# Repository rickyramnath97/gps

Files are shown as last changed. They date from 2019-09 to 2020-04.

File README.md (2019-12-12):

# Build Instructions for Raspberry Pi GPS Sensor

## Table of Contents
1. [Introduction](#introduction)
2. [Material Requirements](#material-requirements)
3. [Raspberry Pi Configuration](#raspberry-pi-configuration)
4. [Mechanical Assembly and Soldering](#mechanical-assembly-and-soldering)
5. [SPI/UART Connection](#spi/uart-connection)
6. [Power Up](#power-up)
7. [Explore with your Sensor](#explore-with-your-sensor)

### Introduction
GPS sensors are receivers with antennas that use a satellite-based navigation system with a network of 24 satellites in orbit around the earth to provide position, velocity, and timing information. The breakout is built around the MTK3339 chipset, a high-quality GPS module that can track up to 22 satellites on 66 channels, has an excellent high-sensitivity receiver (-165 dBm tracking!), and a built in antenna. It can do up to 10 location updates a second for high speed, high sensitivity logging or tracking. Power usage is incredibly low, only 20 mA during navigation. The following instructions are provided to assist you in developing a GPS sensor that can measure longitude, latitude and many other readings.
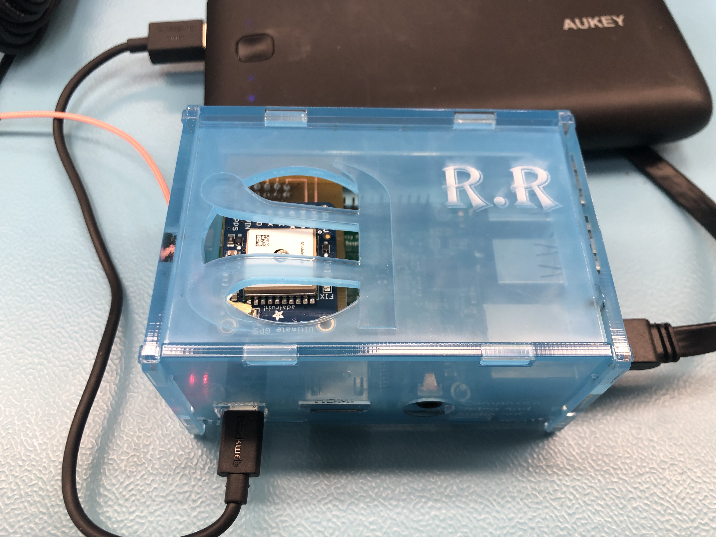
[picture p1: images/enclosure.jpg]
<br/></p>

> I recommend that before attempting this build that you have accomplished watching videos on [soldering](https://youtu.be/3230nCz3XQA). 

### Material Requirements
The project's total budget will cost you approx. CAD$218.41 including tax and shipping. The prices can be converted depending on where you are from. If you would like to see my personal budget click [here](https://github.com/rickyramnath97/gps/blob/master/documentation/Rickys%20Budget.xlsx). Keep in mind that my budget costs lower because I own some of the parts (or had access to in Prototype Lab) from the list.
The following links below are sources of where you can purchase the items:
* [Raspberry Pi 3 Kit](https://www.canakit.com/raspberry-pi-3-ultimate-kit.html) - CAD$89.95
* [Adafruit Ultimate GPS Breakout](https://www.adafruit.com/product/746) - CAD$39.95
* [40 Pin GPIO Connector Header](https://www.buyapi.ca/product/40-pin-gpio-connector-header/) - CAD$1.95
* [Break Away Headers - Straight](https://www.sparkfun.com/products/116) - CAD$2.01
* [Custom PCB](https://www.pcbway.com/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) - CAD$88.88 
<br/>Depending on the design of your PCB prices may vary. 
<br/>You can design your own PCB using [Fritzing](http://fritzing.org/download/) for free. 
<br/>Check out my design of the [PCB](https://github.com/rickyramnath97/gps/tree/master/electronics).
* [Safety Glasses](https://www.amazon.ca/3M-Virtua-Glasses-Polycarbonate-Anti-Scratch/dp/B00AEFBLW2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) - CAD$9.27

### Raspberry Pi Configuration
1. Create your Raspberry Pi's [image](https://github.com/six0four/StudentSenseHat/blob/master/cribpisdcard.md) for your project.

### Mechanical Assembly and Soldering
1. Make sure to break the 9 pins from the Break Away Header. Then start by soldering the sensor to the pins of the header. 
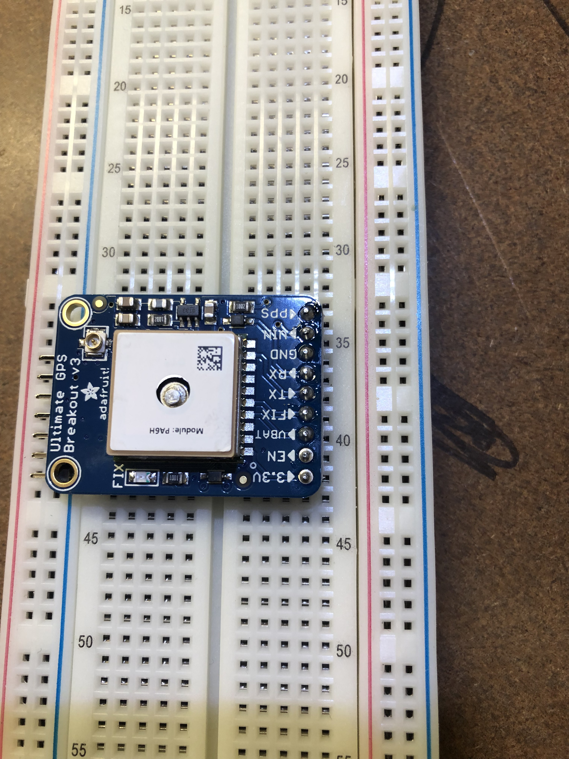
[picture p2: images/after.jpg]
<br/>

2. You can design your own PCB using [Fritzing software](http://fritzing.org/download/) for free or my version of the [fritzing file](https://github.com/rickyramnath97/gps/tree/master/electronics). You can refer to the image of the schematic and PCB designs below.
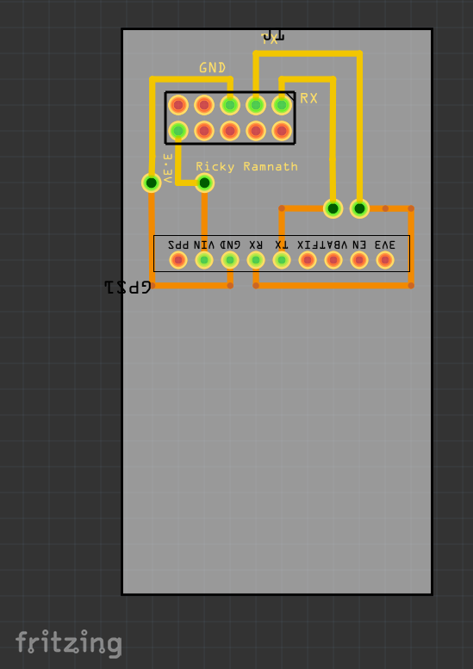
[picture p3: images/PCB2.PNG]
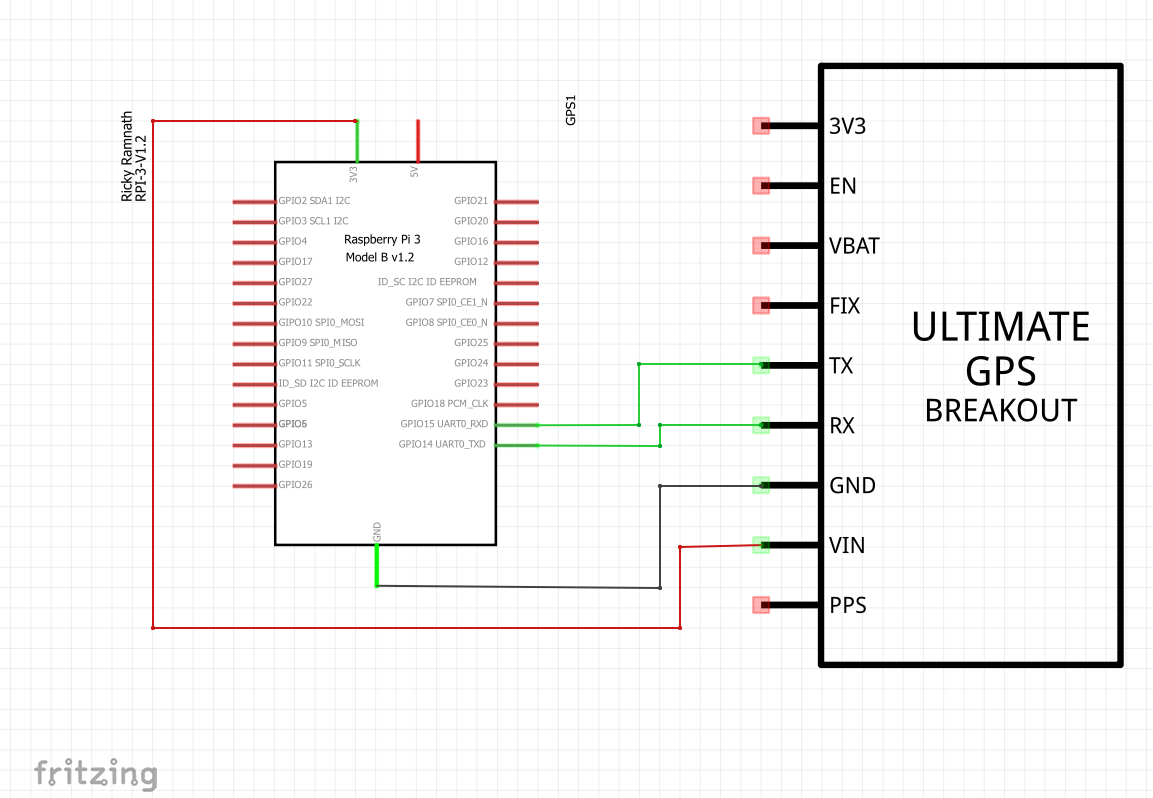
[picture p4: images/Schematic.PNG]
<br/> 
<br/>Here are the following pins that you should know for this project:
##### Power Pins
* VIN - Power Pin
  *GPS Vin  to 3.3V (red wire)
* GND - common ground for power and logic

##### Logic Pins
* RX pin
	* GPS RX to TX on Pi
* TX pin
	* GPS TX to RX on Pi

3. Once you have obtained your PCB board solder the following:
* Vias\*
* 40-pin socket 
* 9-pin socket
<br/>\*Note: You must thread a single strand of wire through the holes, solder it, and then cut the remaining wires off.

Once you have finished soldering, your board should look like this along with the sensor:
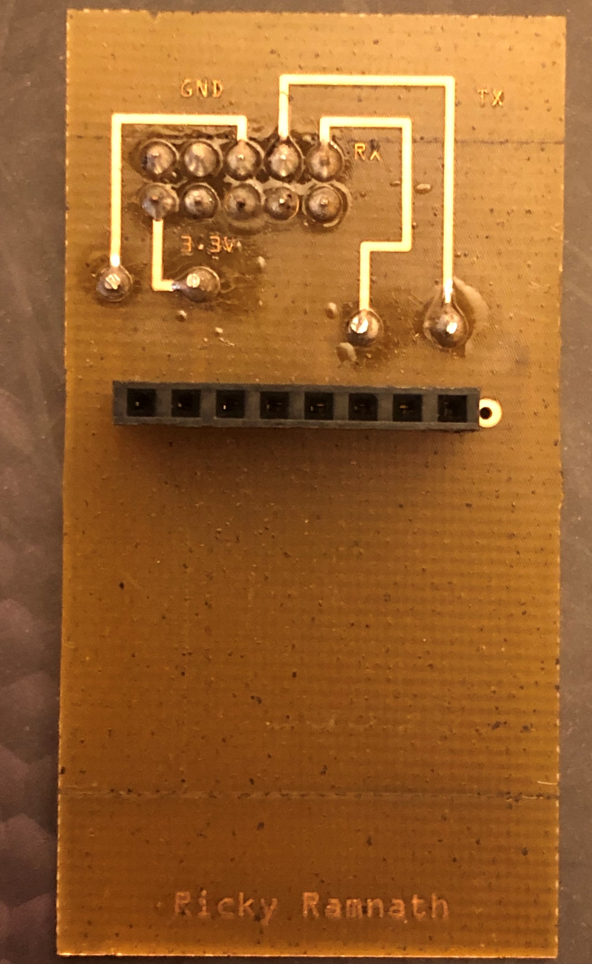
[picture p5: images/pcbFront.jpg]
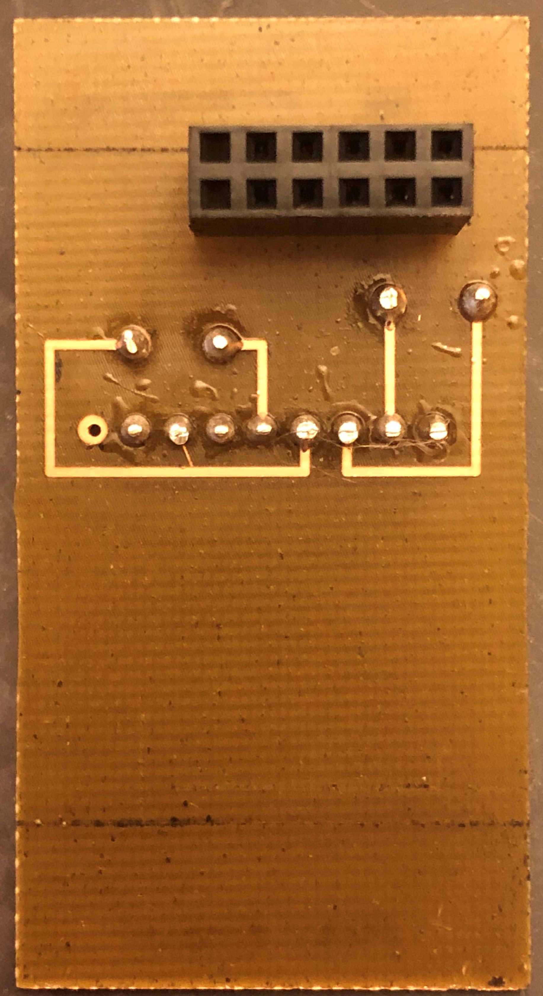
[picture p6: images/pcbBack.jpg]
<br/><br/>

### SPI/UART Connection

1. In order for the sensor to work, you have to Disable Serial console and Enable UART on your Pi. By running <b>sudo raspi-config</b> in the terminal window. Next goto <b>Interfacing Options -> Serial -> Select "No" on enabling the login shell -> Select "Yes" on enabling serial port hardware</b>
This is what it should look like:
<br/>

### Power Up

1. Now you can test the sensor and get readings by typing in the following:
```
sudo killall gpsd
```
```
sudo gpsd /dev/serial0 -F /var/run/gpsd.sock
```
```
cgps -s
```
You should see something like this:
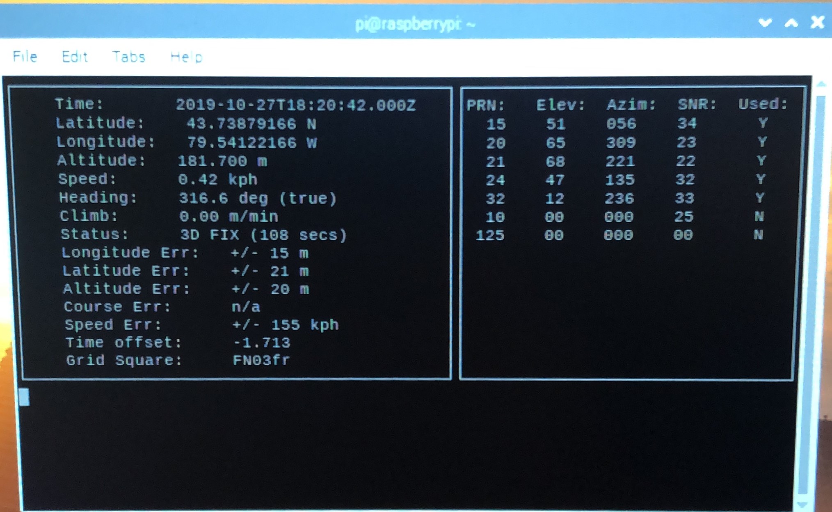
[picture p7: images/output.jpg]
<br/>

### Explore with your Sensor
You can now conduct experiments with your GPS sensor. 

By following these instructions, this project can be reproducible by anybody that has a basic understanding of computers and hardware.

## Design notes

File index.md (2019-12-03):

<h3 id="december-03-2019-week-13">December 3, 2019 (Week 13)</h3>
<p>Presentation Day + Update on Project</p>

<p>Today I presented my final hardware project. I also had to update something in m project. </p>

<p>I needed to get a faster fix for my sensor. In order to combat that I used another type of antenna that I had at home that came with my surveillance camera system. This antenna was able to get a better fix with my GPS due to the protruding antenna. </p>

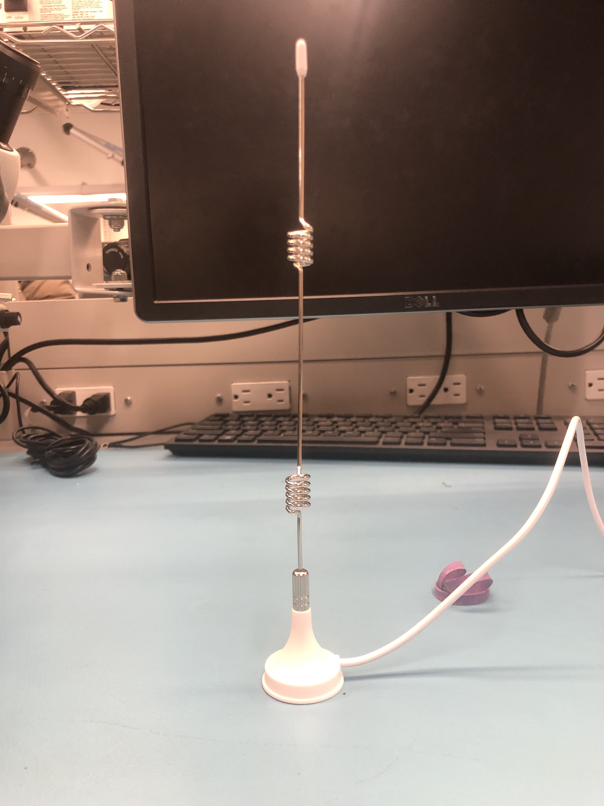
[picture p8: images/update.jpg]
<br/>

<p>I am also working on my README.md file to conclude this semester with. </p>

<hr size="10" width="100%" align="center" color="green">
<h3 id="november-26-2019-week-12">November 26, 2019 (Week 12)</h3>

<p>Presentation Due</p>

<p>This has been an amazing semester. Ive learned alot of new skills.</p>
<p>To conclude this semester, I made a powerpoint presentation which will be graded.</p>
<p>You can view the presentation <a href="https://github.com/rickyramnath97/gps/blob/master/documentation/MTK3339%20%E2%80%93%20Adafruit%20Ultimate%20GPS%20Sensor.pptx">here</a></p>

<hr size="10" width="100%" align="center" color="green">
<h3 id="november-19-2019-week-11">November 19, 2019 (Week 11)</h3>
<p>Enclosure Due</p>
<p>This week I am showing that my Enclosure is due. I used CorelDRAW and some of the internet to help me design my case. You can view my design file <a href="https://github.com/rickyramnath97/gps/blob/master/mechanical/RickysPi3Case%20New.cdr">here</a></p>

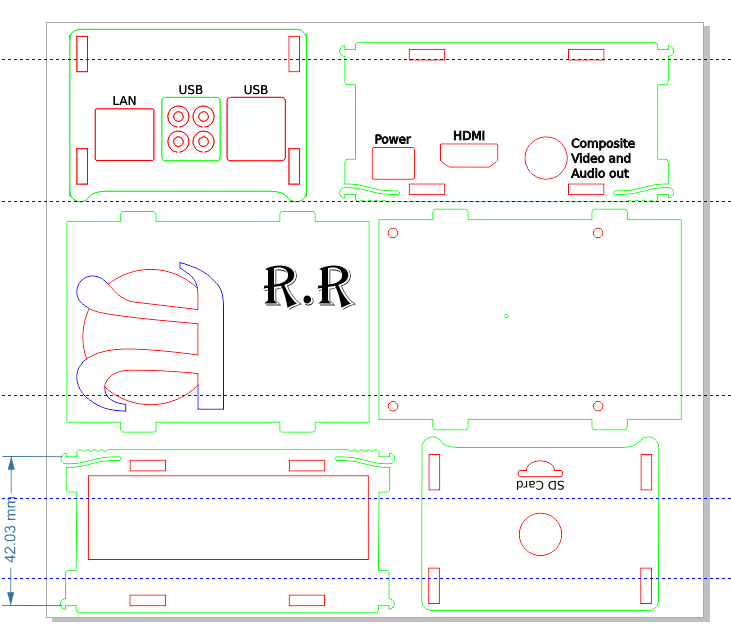
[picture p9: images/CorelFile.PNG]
Schematic

Enclosure

<hr size="10" width="100%" align="center" color="green">
<h3 id="november-12-2019-week-10">November 12, 2019 (Week 10)</h3>
<p> PCB Power Up </p>
<p> This week I powered up my PCB and tested it. I was having some trouble aquiring signal for my GPS at school. I have found a spot where is located in the prototype lab where it has worked before. I am still actively looking and trying to find "sweet spots" around the vicinity of the class room and inside the prototype lab. So far everything is working fine though. </p>
<p> Referring to my Gantt Chart, I am up to date with everything and I am in the process of making my enclosure for my RPi which is due next week and will be graded. </p>
<p> Below you can see a video of my sensor working with my PCB. </p>
<video width="420" height="420" controls>
  <source src="videos/PCB_PowerUp.mp4" type="video/mp4">
  Your browser does not support HTML5 video.
</video>

<hr size="10" width="100%" align="center" color="green">
<h3 id="november-5-2019-week-9">November 5, 2019 (Week 9)</h3>
<p> Soldering Milestone </p>
<p> Soldered up my PCB Board that was made in the Protoype Lab </p>
<p> According to my Gantt Chart, I am up to date with my progress and have my sensor and my connection from my laptop to my RPi working seemlessly. </p>
<p> This week I am working on designing my enclosure to fit my sensor and my Development Platform. I have done the Idea Lab Quiz and booked a session to get more information as to how it will all work. </p>
<p> Below are photos of my PCB soldered up. I used a 8-Pin Stackable Header to harness my GPS Sensor, and used a 6x2 Stackable Header to plug into my RPi. All the connections are flawless. There are no bridges. To test it, I used my digital multimeter to test continuity to see if any contacts are bridged. </p>
Front of PCB
Back of PCB

<hr size="10" width="100%" align="center" color="green">
<h3 id="october-29-2019-week-8">October 29, 2019 (Week 8)</h3>
<p> Breadboarded Milestone: This week I successfully breadboarded and demostrated my sensor in front of my Professor(Kristian). I also spent some time in the prototype lab with Kelly and Kristian to set up my RPI to get it to connected to my laptop using a ethernet cable and adapter (was a success). So far, from refering to my Gantt Chart, I am on track with all my milestones and achievements. </p>
<p> Sensor Breadboarded: </p>
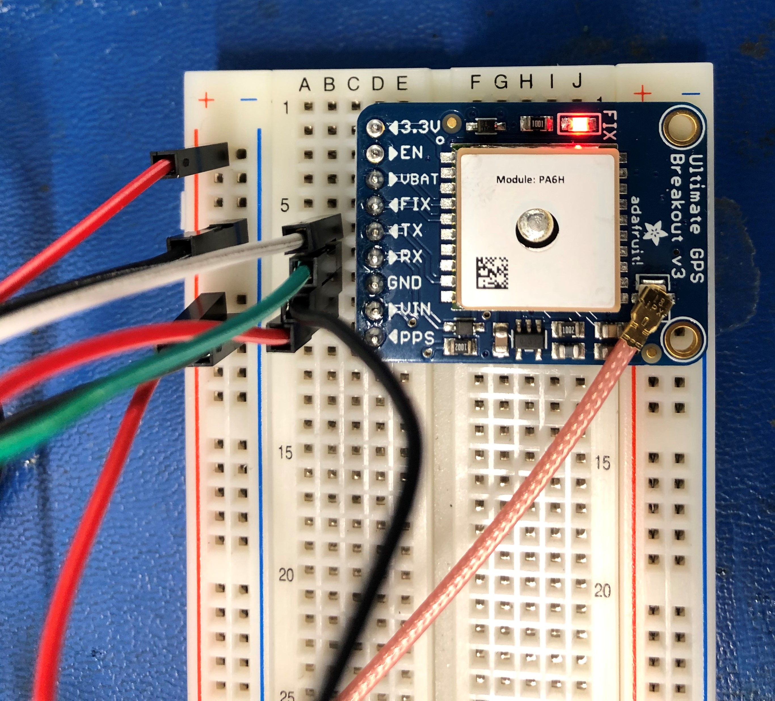
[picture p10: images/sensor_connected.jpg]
Connected Sensor

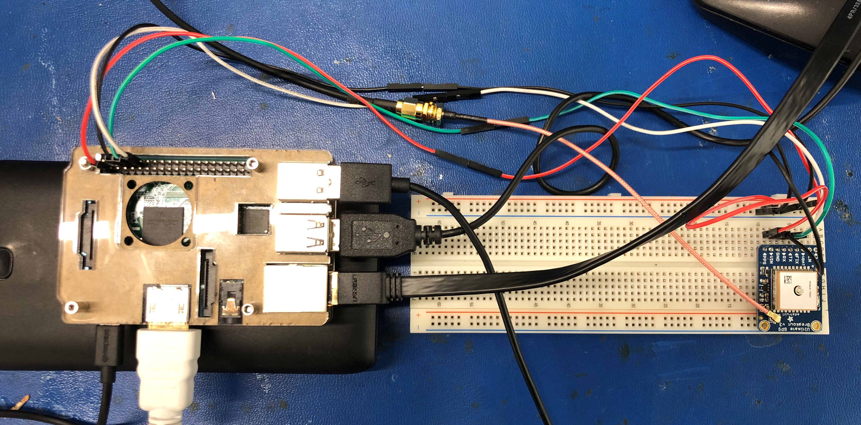
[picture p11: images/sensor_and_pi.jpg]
Sensor and Pi


<p> In order for my sensor to work, I had to Disable Serial console and Enable UART on my Pi. By running <b>sudo raspi-config</b> in the terminal window. Next I went to <b>Interfacing Options -> Serial -> Select "No" on enabling the login shell -> Select "Yes" on enabling serial port hardware</b></p>
<p> This is what I got: </p>
Config

<p> Next I ran a few commands to get the the sensor to display its respective results: </p>
<p><b> sudo killall gpsd </b></p>
<p><b> sudo gpsd /dev/serial0 -F /var/run/gpsd.sock </b></p>
<p><b> cgps -s </b></p>

<p> These are the results I got: </p>
Output
<hr size="10" width="100%" align="center" color="green">
<h3 id="october-15-2019-week-7">October 15, 2019 (Week 7)</h3>
<p> PCB Designed </p>
<p> Designed my PCB, Schematic, and Breadboard Design. I also sent my gerber files to the Prototype Lab. You can view my fritzing file <a href="https://github.com/rickyramnath97/gps/blob/master/electronics/GPS%20Fritzing2.fzz">here</a>. </p>
<p> I am also getting my Broadcom Development Platform set up with VNC Viewer to work with the Humber College WiFi network. </p> 
<p>PCB Designed: </p>
Image of PCB
<p>Schematic: </p>
Image of Schematic
<p>Breadboard Design: </p>
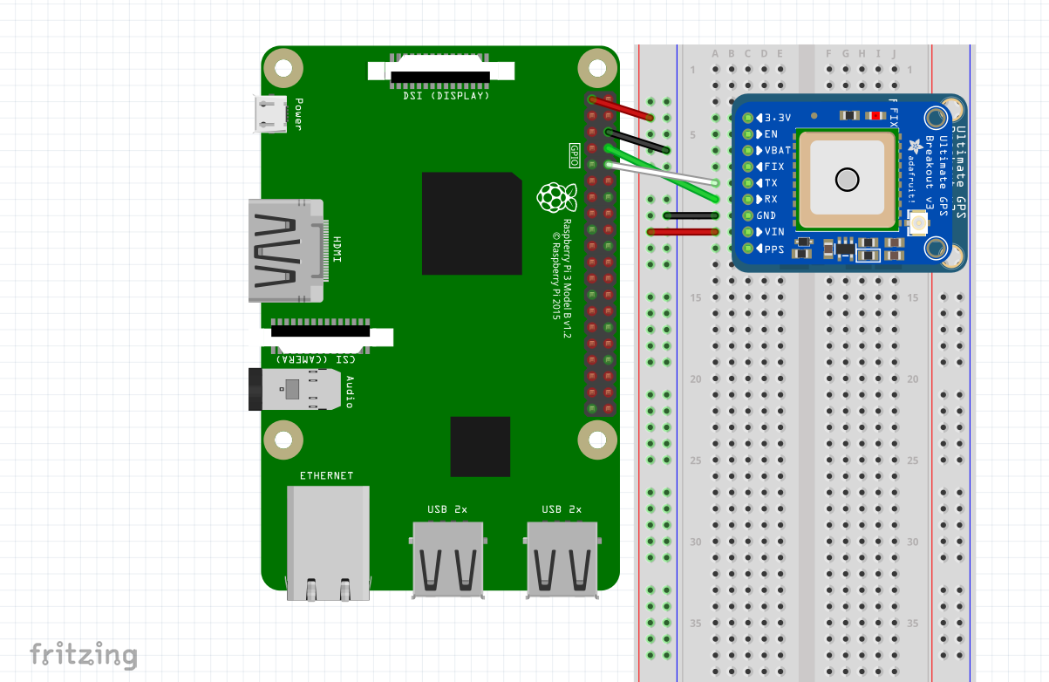
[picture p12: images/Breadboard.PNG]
Image of Breadboard


<hr size="10" width="100%" align="center" color="green">

<h3 id="october-8-2019-week-6">October 8, 2019 (Week 6)</h3>
<p> Showing my acquisitions </p>
<p> Package arrived Thursday, October 3rd, 2019: </p>
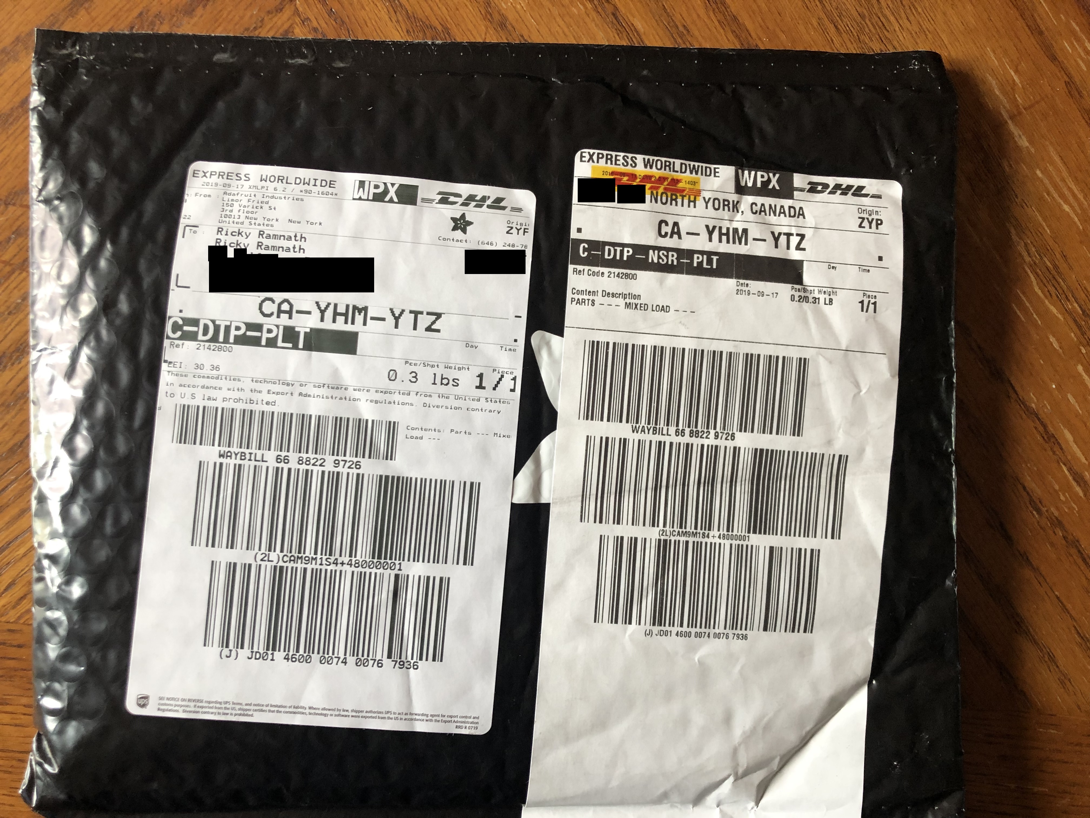
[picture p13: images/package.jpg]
Image of Package


<p> Contents of package include; GPS Sensor, Adapter cable for antenna, and antenna: </p>

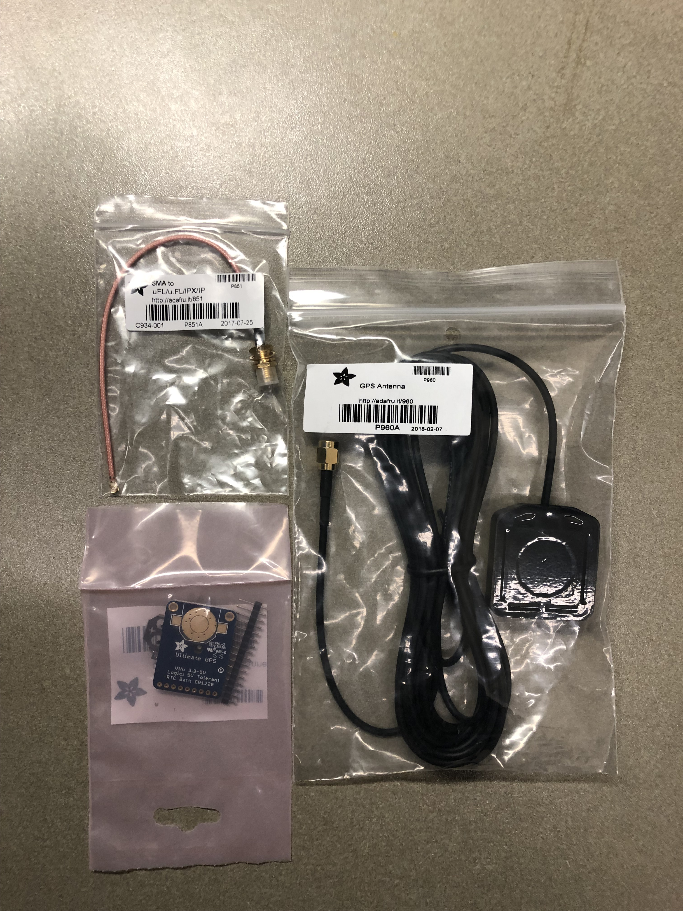
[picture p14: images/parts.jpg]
Image of parts


<p> I had also watched a <a href="https://youtu.be/3230nCz3XQA">video</a> on how to solder my header pins and was able to do so. I used my own Lead Free solder with Rosin Core and a soldering iron that I had borrowed from work. This was the outcome:</p>

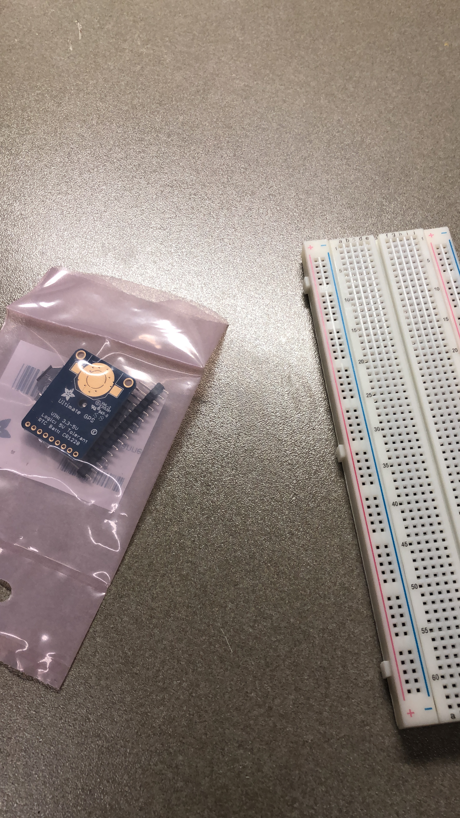
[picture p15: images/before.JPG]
Image of parts


Image of parts

<hr size="10" width="100%" align="center" color="green">

<h3 id="october-1-2019-week-5">October 1, 2019 (Week 5)</h3>
<p> Setting up my broadcom development platform (RPI) </p>
<p> Parts Ordered </p>

<p> Proof of Purchase: </p>
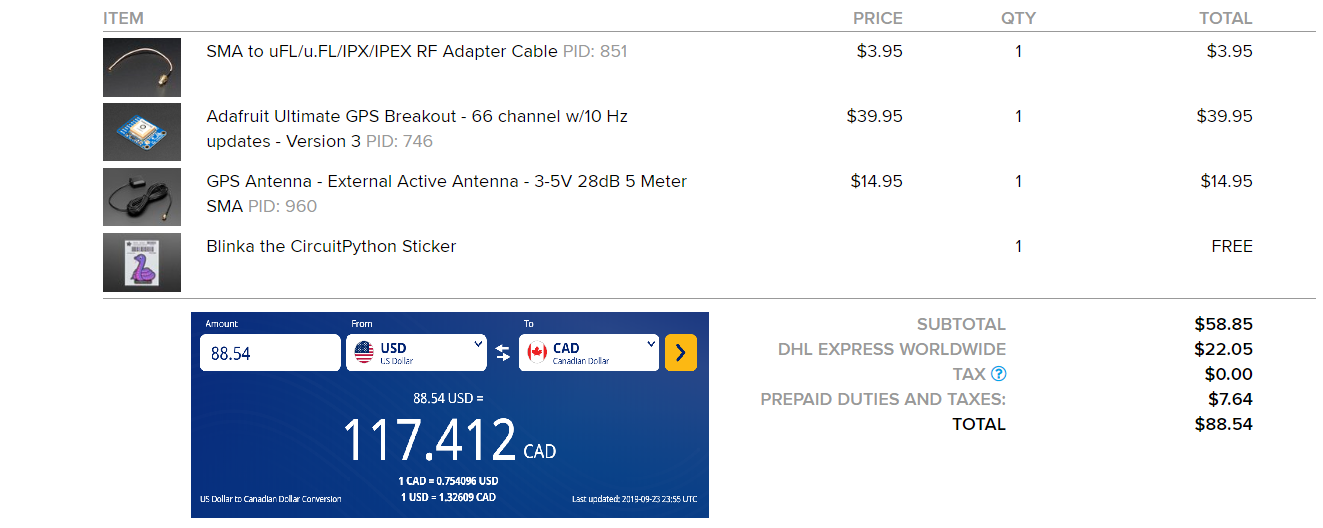
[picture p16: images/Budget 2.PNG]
Image of Budget


<hr size="10" width="100%" align="center" color="green">

<h3 id="september-24-2019-week-4">September 24, 2019 (Week 4)</h3>
  
<p><a href="https://github.com/rickyramnath97/gps/blob/master/documentation/Rickys%20Budget.xlsx">Budget Completed!</a>.</p>
  <p>- Ordered Parts</p>

<hr size="10" width="100%" align="center" color="green">

<h3 id="september-17-2019-week-3">September 17, 2019 (Week 3)</h3>
   
<p><a href="https://github.com/rickyramnath97/gps/blob/master/documentation/CENG317%20Project%20Plan.gan">Gantt Chart Completed!</a></p>
 <p>- Met with collaborators </p> 
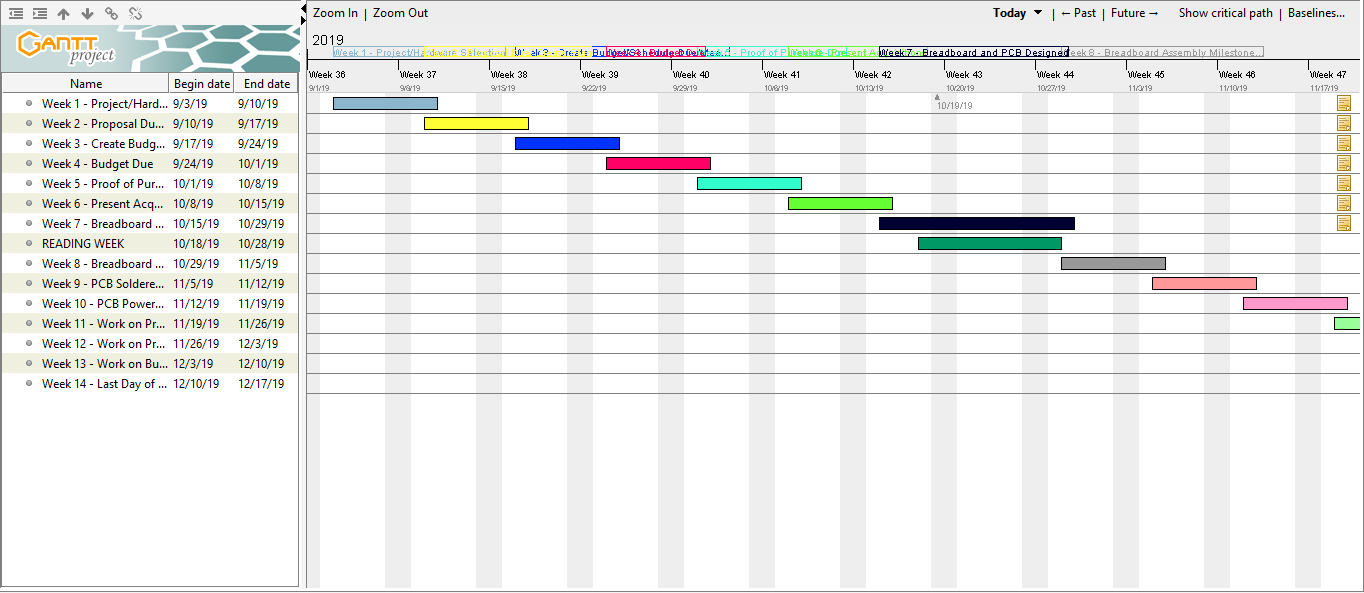
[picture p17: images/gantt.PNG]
Gantt


<hr size="10" width="100%" align="center" color="green"> 
  
<h3 id="september-09-2019-week-2">September 9, 2019 (Week 2)</h3>

<p> Handed in <a href="https://github.com/rickyramnath97/gps/blob/master/documentation/ProposalContentStudentNameRev03.xlsx">proposal</a>. </p>

<p> For my hardware, I chose the Adafruit Ultimate GPS Breakout. This will be able to display location. My goal is to make the project scalable from one location to several for our Capstone Project. To enhance the user experience, having a GPS Sensor is crucial to detect which parts crib data belong to which. Additionally, the GPS will prioritize orders by accessing location from students and finding out how long it will take for student to arrive to the parts crib. From that we will know which orders to get ready first in priority sequence based on travel time. </p>

<p> Image of Sensor: </p>
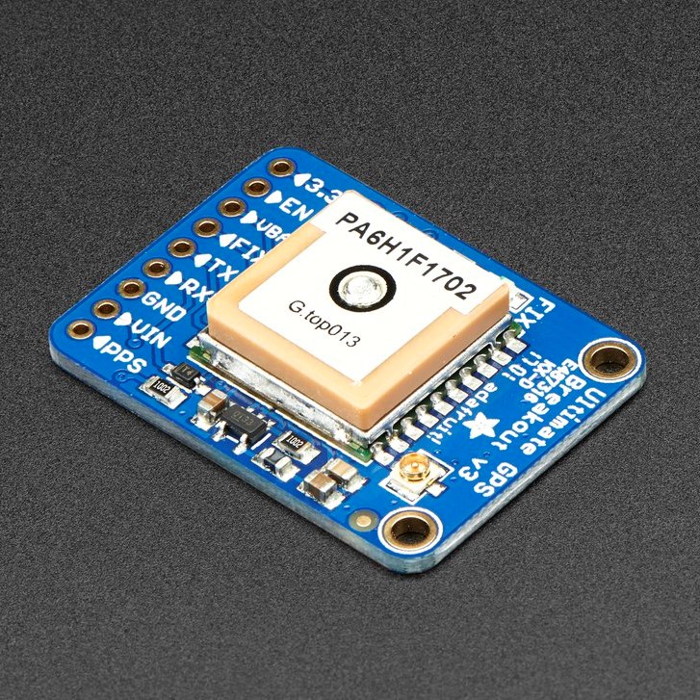
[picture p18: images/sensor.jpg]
Image of Sensor


<p> Working on Gantt Chart </p>

<hr size="10" width="100%" align="center" color="green">

<h3 id="september-03-2019-week-1">September 3, 2019 (Week 1)</h3>

<p>Welcome! </p>
<p>Repo Created! </p>

<p>Created <a href="https://github.com/rickyramnath97/gps/blob/master/documentation/ProposalContentStudentNameRev03.xlsx">proposal</a>.</p>

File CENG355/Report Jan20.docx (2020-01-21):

Ricky Ramnath

Humber College Parts Crib Management Solution

Status

/1 Hardware present?

/1 Title Page

/1 Declaration of Joint Authorship

/1 Proposal (500 words)

/1 Executive Summary

# Declaration of Joint Authorship

We, Student A, Student B, and Student C, confirm that this work submitted is the joint work of our group and is expressed our own words. Any uses made within it of the works of any other author, in any form (ideas, equations, figures, texts, tables, programs), are properly acknowledged at the point of use. A list of the references used is included. The work breakdown is as follows: Each of us provided functioning, documented hardware for a sensor or effector. Student A provided RFID Scanner. Student B provided GPS Sensor. Student C provided 12- Button Keypad. In the integration effort Student A is the lead for further development of our mobile application, Student B is the lead for the Hardware, and Student C is the lead for connecting the two via the Database.

# Proposal

We have created a mobile application, worked with databases, completed a software engineering course, and prototyped a small embedded system with a custom PCB as well as an enclosure (3D printed/laser cut). Our Internet of Things (IoT) capstone project uses a distributed computing model of a smart phone application, a database accessible via the internet, an enterprise wireless (capable of storing certificates) connected embedded system prototype with a custom PCB as well as an enclosure (3D printed/laser cut), and are documented via this technical report targeting OACETT certification guidelines.

Intended project key component descriptions and part numbers
Development platform:
Sensor/Effector 1: RFID Scanner
Sensor/Effector 2: GPS Sensor
Sensor/Effector 3: 12 Button Keypad

We will continue to develop skills to configure operating systems, networks, and embedded systems using these key components to create an easier and more efficient method for allowing students to borrow parts from The Parts Crib. This project consists of both a web application and a mobile application with our sensors/effectors. The mobile application provides convenient access for students. This will be beneficial to students as they will be able to utilize the app to find parts that are available. They will be able to view the inventory of available parts which they can borrow if they wish, by using their student credentials. The web application will be utilized mainly by administrative users to keep track of inventory. The overall goal of this project is to avoid overcrowding in The Parts Crib during peak hours of the lab, keep track of parts that have yet to be returned by certain students based on their student credentials and to keep track of the remaining inventory. The RFID Scanner will be used to scan in and out parts that will be recorded on the online database which helps to provide inventory status. The GPS Sensor will prioritize the orders by location and help to identify a more specific location for The Parts Crib. The 12 Button Keypad will be used to get new registered users to type in a specific randomly generated code into the application upon registration to verify that they identify as a Humber College Student.

Our project description/specifications will be reviewed by, _____, ideally an employer in a position to potentially hire once we graduate. They will also ideally attend the ICT Capstone Expo to see the outcome and be eligible to apply for NSERC funded extension projects. This typically means that they are from a Canadian company that has been revenue generating for a minimum of two years and have a minimum of two full time employees.

The small physical prototypes that we build are to be small and safe enough to be brought to class every week as well as be worked on at home. In alignment with the space below the tray in the Humber North Campus Electronics Parts kit the overall project maximum dimensions are 12 13/16" x 6" x 2 7/8" = 32.5cm x 15.25cm x 7.25cm.

Keeping safety and Z462 in mind, the highest AC voltage that will be used is 16Vrms from a wall adapter from which +/- 15V or as high as 45 VDC can be obtained. Maximum power consumption will not exceed 20 Watts. We are working with prototypes and that prototypes are not to be left powered unattended despite the connectivity that we develop.

# Executive Summary

Explain what accomplishments are described by this document and why your product should be purchased and you should be hired by an investor.

# List of Figures

# 1.0 Introduction

This technical report presents the methods and processes of how we achieved our project result. Knowing who arrives, borrows parts and having easy access to our inventory are key parts of the parts crib management solution. Some of this projects policy require that you track how long students are borrowing parts for or that all students participating return each part at a certain time of day that is specified. This will additionally be able to help the administrative side by verifying that individuals borrowing parts are Humber College students that have an official student ID card. By recording sign-out times, it’s easy to track who borrows parts when and attend to students who are over their time limit or that have not yet returned said parts. Having a GPS sensor to track activity from a certain parts crib location and prioritize orders will also help with an efficient way of managing the parts crib. To further enhance security, the keypad will allow students to enter the specific code that will be generated by the application to ensure verification of Humber students. Finally, the RFID scanner will be a critical component of this project to help keep track of inventory by uploading information to the database for a more accurate count and to easily monitor activity. The application will provide a precise GPS location of the parts cribs, inventory status, and peak times for labs. The application will also allow students to create a cart of parts they will need for their labs and place orders from anywhere with a Wi-Fi connection. This system is meant for loan out companies and small businesses with inventory that will need to be loaned out to employees or customers. Specifically, this system will be prototyped and used by the Humber College Parts Crib.

## 1.1 Scope and Requirements

Describe what will be done. It is an Internet of Things (IoT) capstone project that uses a distributed computing model of a smart phone application, a database accessible via the internet, an enterprise wireless (capable of storing certificates) connected embedded system prototype with a custom PCB as well as an enclosure (3D printed/lasercut), and is documented via an OACETT certification acceptable technical report. Also describe the limits of the project and what will not be done (CSA testing) in this project. Include the development platform specifications and any other hardware specifications possibly organized in point form, the Android device requirements, and database specifications/protocols.

Report

/1 Hardware present?

/1 Introduction (500 words)

/1 Scope and Requirements

/1 Background (500 words)

/1 References

# 2.0 Background

We would like to thank mentor Diego Magalhães from AWS for supporting this project. This section is to include at least three references, here is an example of an APA citation of a website (OACETT, 2017) followed by a sentence citing an Article in a Periodical, a Book, and a Journal Article. Humber is planning to host an internal DeepRacer event using an existing example of machine learning (Robuck, 2018), artificial intelligence (Media, O., 2019), and internet connected servers (Kinsella, 2019).

# 3.0 Methodology

## 3.1 Required Resources

Report

/1 Parts/components/materials (500 words)

/1 PCB, case (500 words)

/1 Tools, facilities (500 words)

/1 Shipping, duty, taxes (250 words)

/1 Working time versus lead time (250 words)

### 3.1.1 Parts, Components, Materials

### 3.1.2 Manufacturing

### 3.1.3 Tools and Facilities

### 3.1.4 Shipping, duty, taxes

### 3.1.5 Time expenditure

Working time versus lead time.

## 3.2 Development Platform

### 3.2.1 Mobile Application

Status

/1 Hardware present?

/1 Memo by student A + How did you make your Mobile Application? (500 words)

/1 Login activity

/1 Data visualization activity

/1 Action control activity

Include screenshots such as Figure 1. Testing. Progress.

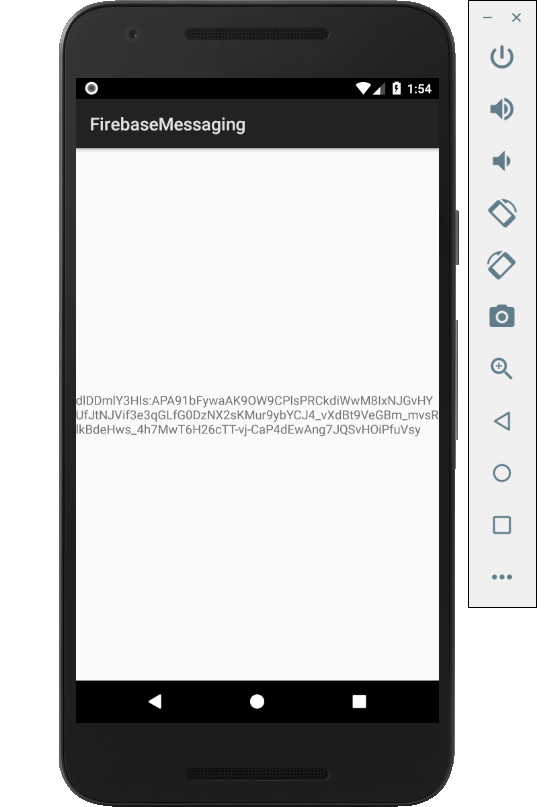
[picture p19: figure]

Figure 1. By Android Studio - https://developer.android.com/studio/, CC BY-SA 4.0, https://commons.wikimedia.org/w/index.php?curid=74094999

### 3.2.2 Image/firmware

Status

/1 Hardware present?

/1 Memo by student B + How did you make your Image/firmware? (500 words)

/1 Code can be run via serial or remote desktop

/1 Wireless connectivity

/1 Sensor/effector code on repository

### 3.2.3 Breadboard/Independent PCBs

Status

/1 Hardware present?

/1 Memo by student C + How did you make your hardware? (500 words)

/1 Sensor/effector 1 functional

/1 Sensor/effector 2 functional

/1 Sensor/effector 3 functional

The initial schematic design, Figure 2, based on datasheets (Bosch Sensortec, 2019) led to a breadboard layout Figure 3 that was realized Figure 4.

How did you build your Prototype: Breadboard?

Then a PCB was designed, Figure 5, and populated (Figure 6). Bill of Materials, Case, Time commitment. Testing. Progress.

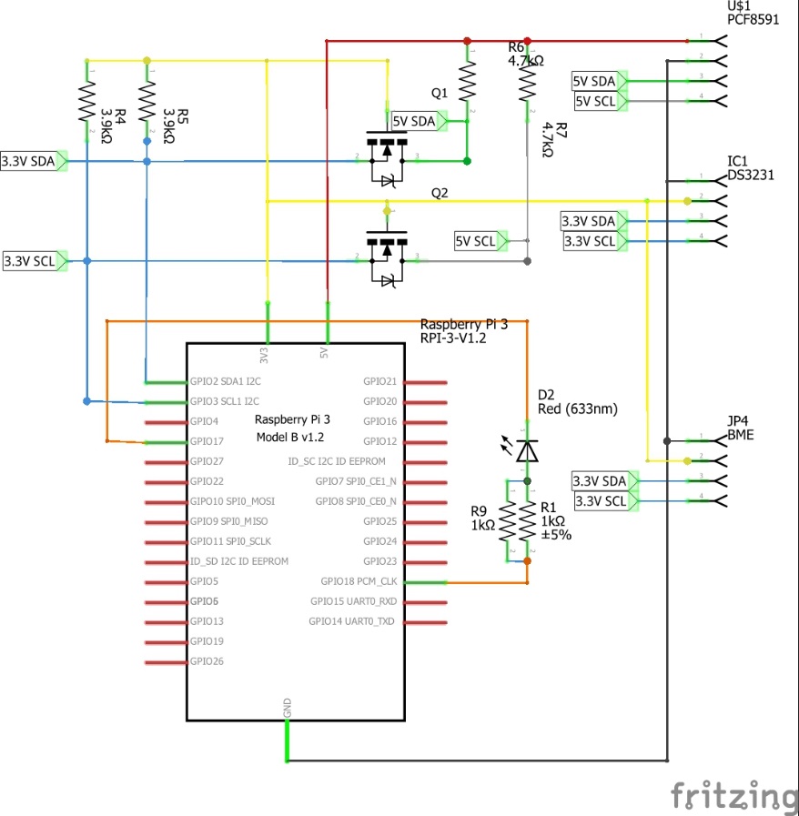
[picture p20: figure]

Figure 2. Initial schematic. This work is a derivative of "http://fritzing.org/parts/" by Fritzing, used under CC:BY-SA 3.0.

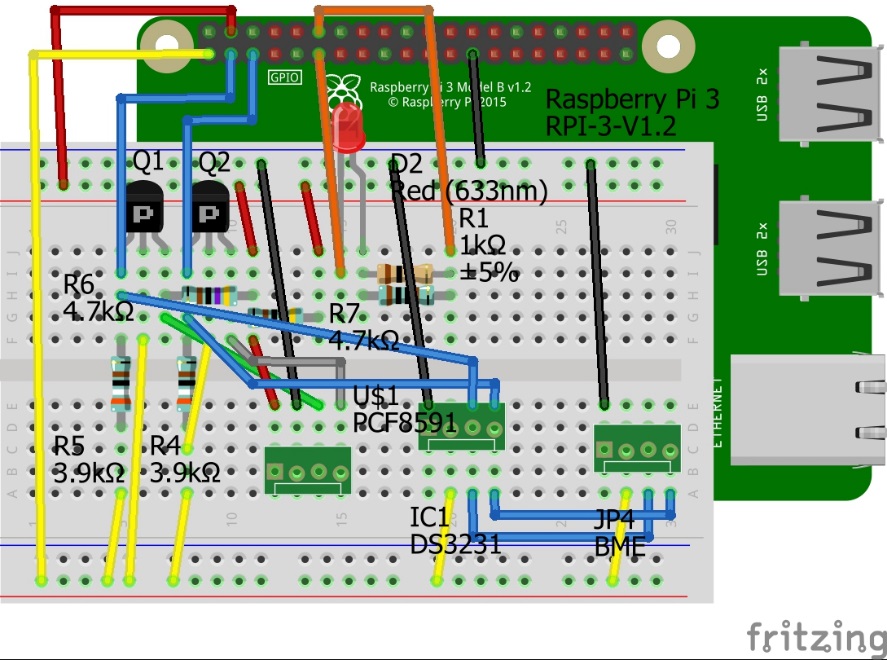
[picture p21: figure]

Figure 3. This work is a derivative of "http://fritzing.org/parts/" by Fritzing, used under CC:BY-SA 3.0.

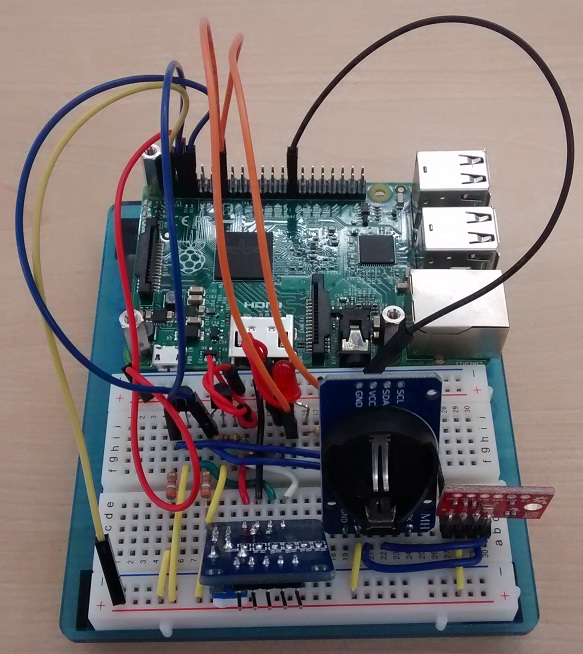
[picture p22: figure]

Figure 4. Breadboard prototype.

### 3.2.4 Printed Circuit Board

Demo

/1 Hardware present?

/1 PCB Complete and correct

/1 PCB Soldered wire visible but trim, no holes or vacancies

/1 PCB Tested with multimeter

/1 PCB Powered up

How did you build your Prototype: PCB?

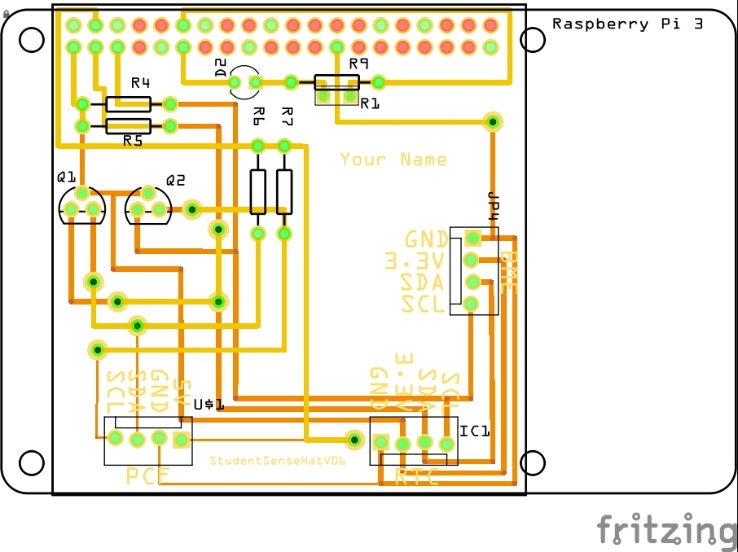
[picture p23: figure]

Figure 5. PCB design This work is a derivative of "http://fritzing.org/parts/" by Fritzing, used under CC:BY-SA 3.0.

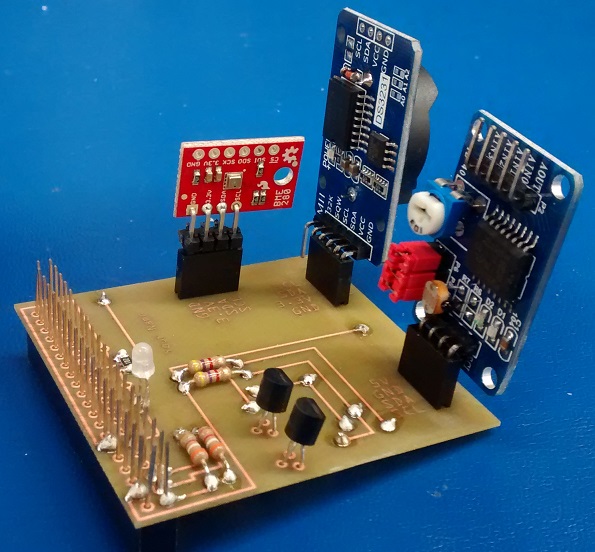
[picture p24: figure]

Figure 6. Humber Sense Hat Prototype PCB.

### 3.2.5 Enclosure

Demo

/1 Hardware present?

/1 Case encloses development platform and custom PCB.

/1 Appropriate parts securely attached.

/1 Appropriate parts accessible.

/1 Design file in repository, photo in report.

How did you build your Prototype: Case?

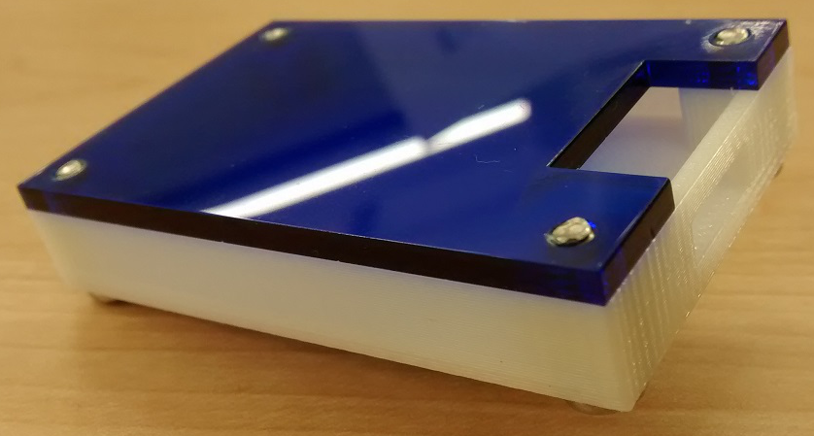
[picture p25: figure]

Figure 7. Example enclosure.

## 3.3 Integration

Demo

/1 Hardware present?

/1 Data sent by hardware

/1 Data retrieved by mobile application

/1 Action initiated by mobile application

/1 Action recieved by hardware

Report

/1 Enterprise wireless connectivity (250)

/1 Database configuration (250 words)

/1 Security considerations (500 words)

/1 Unit testing (900 words)

/1 Production testing (100 words)

### 3.3.1 Enterprise Wireless Connectivity

How did you make a Database accessible by both your Prototype and Mobile Application?

### 3.3.2 Database Configuration

### 3.3.3 Security

### 3.3.4 Testing

Unit testing and Production testing.

# 4.0 Results and Discussions

Is your prototype perfect? What did you learn?

# 5.0 Conclusions

If you were making 1000 of these.

Report

/1 Hardware present?

/1 Checklist truthful

/1 Valid Comments

/1 Results and Discussion (500 words)

/1 Conclusion

# 6.0 References

Bosch Sensortec. (2019, July). BME680 - Datasheet. Retrieved from Robert Bosch GmbH: https://ae-bst.resource.bosch.com/media/_tech/media/datasheets/BST-BME680-DS001.pdf

Kinsella, J. (2019). Five trends predicted for the cloud industry in 2019. Software World, 50(1), 11.

Media, O. (2019). O'Reilly artificial intelligence conference 2019 - San Jose, California. California: O'Reilly Media, Inc.

OACETT. (2017, March). I need to Complete a Technology Report. Retrieved from The Ontario Association of Certified Engineering Technicians and Technologists: https://www.oacett.org/Membership/Technology-Report-and-Seminar

Robuck, M. (2018, 11). AWS goes deep and wide with machine learning services and capabilities. Fierceinstaller.

# 7.0 Appendix

## 7.1 Firmware code

Demo

/1 Hardware present?

/3 Code runs concurrently for all sensors/effectors

/1 Project repository contains integrated code

Status

/1 Memo including updates

/1 Financial update

/1 Progress update

/1 Modified Code Files in Appendix

/1 Link to Complete Code in Repository

## 7.2 Application code

Demo

/1 Hardware present?

/1 Memo by student A

/1 Login activity

/1 Data visualization activity

/1 Action control activity

Report

/1 Login activity

/1 Data visualization activity

/1 Action control activity

/1 Modified Code Files in Appendix

/1 Link to Complete Code in Repository

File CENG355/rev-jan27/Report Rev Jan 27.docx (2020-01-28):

Ricky Ramnath

Humber College Parts Crib Management Solution

Status

/1 Hardware present?

/1 Title Page

/1 Declaration of Joint Authorship

/1 Proposal (500 words)

/1 Executive Summary

# Declaration of Joint Authorship

We, Student A, Student B, and Student C, confirm that this work submitted is the joint work of our group and is expressed our own words. Any uses made within it of the works of any other author, in any form (ideas, equations, figures, texts, tables, programs), are properly acknowledged at the point of use. A list of the references used is included. The work breakdown is as follows: Each of us provided functioning, documented hardware for a sensor or effector. Student A provided RFID Scanner. Student B provided GPS Sensor. Student C provided 12- Button Keypad. In the integration effort Student A is the lead for further development of our mobile application, Student B is the lead for the Hardware, and Student C is the lead for connecting the two via the Database.

# Proposal

We have created a mobile application, worked with databases, completed a software engineering course, and prototyped a small embedded system with a custom PCB as well as an enclosure (3D printed/laser cut). Our Internet of Things (IoT) capstone project uses a distributed computing model of a smart phone application, a database accessible via the internet, an enterprise wireless (capable of storing certificates) connected embedded system prototype with a custom PCB as well as an enclosure (3D printed/laser cut), and are documented via this technical report targeting OACETT certification guidelines.

Intended project key component descriptions and part numbers
Development platform:
Sensor/Effector 1: RFID Scanner
Sensor/Effector 2: GPS Sensor
Sensor/Effector 3: 12 Button Keypad

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

Our project description/specifications will be reviewed by, _____, ideally an employer in a position to potentially hire once we graduate. They will also ideally attend the ICT Capstone Expo to see the outcome and be eligible to apply for NSERC funded extension projects. This typically means that they are from a Canadian company that has been revenue generating for a minimum of two years and have a minimum of two full time employees.

The small physical prototypes that we build are to be small and safe enough to be brought to class every week as well as be worked on at home. In alignment with the space below the tray in the Humber North Campus Electronics Parts kit the overall project maximum dimensions are 12 13/16" x 6" x 2 7/8" = 32.5cm x 15.25cm x 7.25cm.

Keeping safety and Z462 in mind, the highest AC voltage that will be used is 16Vrms from a wall adapter from which +/- 15V or as high as 45 VDC can be obtained. Maximum power consumption will not exceed 20 Watts. We are working with prototypes and that prototypes are not to be left powered unattended despite the connectivity that we develop.

# Executive Summary

Explain what accomplishments are described by this document and why your product should be purchased and you should be hired by an investor.

# List of Figures

# 1.0 Introduction

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

## 1.1 Scope and Requirements

The parts crib management system will implement a system that will allow the parts crib to keep an electronic catalogue of items loaned out to students. Students will be able to use a mobile android-based application to see what items are available and to request them using their student credentials. An RFID Scanner, GPS Sensor, and a Keypad

System will allow us to achieve this. Our goal is to make this a more efficient and easier way of borrowing parts from the parts crib. It is a goal of our group to make this project industry worthy for any application. We are assuming we’re capable of putting RFID tags on everyone’s student ID in the parts management system. We can also assume that the inventory of the parts crib is given to us so we’re able to put it into our database for when it comes to distribution of parts. We’re dependent on the Admins at the parts crib to be able to read the system and be able to handle the intake of item requests given to them by the users.

/1 Hardware present?

/1 Introduction (500 words)

/1 Scope and Requirements

/1 Background (500 words)

/1 References

# 2.0 Background

The Humber College Parts Crib is located in a hallway in the J building at Humber College, it’s situated near the main series of labs, as well as classrooms, used by students of the Electrical/Electronic/Computer Engineering Technology programs. The current lending system was implemented by Vlad Porcila to address issues he saw with the lending process at The Parts Crib. The system requires that students make a request on a network-connected school computer using an application. This request is then made visible in a queue of requests to Parts Crib staff. The student is then expected to come to the parts crib, present their school ID and pick up the requested parts which will have been placed in a clear bag with an RFID tag assigned to that student.

The main concerns that the Parts Crib Staff feel need to be addressed, are the amount of time spent verifying student identification, notifying students when their parts are ready to be picked up (to avoid unnecessary crowding by students who are waiting for their request to be fulfilled), a way to prioritize orders based on when a student might need the parts, and the ability to retrieve historical data.

The challenges faced by the Parts Crib are similar to those encountered when handling lending services at libraries and item tracking at logistics companies. IoT technologies are being adopted at an increasing rate in supply chain management. The key technologies being deployed are RFID tag systems, cloud computing and IoT applications allowing multiple devices to communicate with one another Ben-Daya, Hassini, Bahroun 2017). One of the most common configurations used by companies for RFID tracking of shipments is to have each RFID tag assigned to a case/pallet (Zelbst, Sower 2012. p.73). This is analogous to the bagging system currently used by The Parts Crib, and with information about the items contained in the bag being stored in a cloud database it minimizes the number of RFID tags required.

In order to limit the interaction between a student and the Parts Crib staff during the process of obtaining loan requests we will require students to have a RFID tag affixed to their Humber student ID and the web/android application will generate a 5 digit pin for each request that they’ll be required to enter after tapping their card. This system is known as a smart card based two-factor authentication scheme and has the advantage of being easy to scale and cost-effective (Hussain et al. 2019). As the student will return the bag using the RFID tag, the only interaction between staff and students will be the when the staff hand the designated bag of items to the students.

We would like to thank Kristian Medri, Austin Tian for providing us with support during the writing of this report as well as overseeing our work on the application/website and physical prototype and Vlad Porcilo for meeting with us during project milestones to provide further input into features The Parts Crib staff would like to see.

# 3.0 Methodology

## 3.1 Required Resources

Report

/1 Parts/components/materials (500 words)

/1 PCB, case (500 words)

/1 Tools, facilities (500 words)

/1 Shipping, duty, taxes (250 words)

/1 Working time versus lead time (250 words)

### 3.1.1 Parts, Components, Materials

There will be many parts, components, and materials that will be used in this project. Firstly, there will be the sensors which include; the radio frequency identification scanner, global position sensor, and a twelve-button keypad. Each sensor and effector will be a key asset to this project. Some materials that will be used will include, laser cut acrylic, fiberglass epoxy resin with a copper foil bonded on to one or both sides which is what the printed circuit board is made of, and acrylonitrile butadiene styrene plastic for the three-dimensional printed parts that will be used with the acrylic to make a feasible enclosure to house our sensors. For our development platform, we will be using a raspberry pi three model b as well as a nucleo STM32 microcontroller. The nucleo stm32 microcontroller will be used alongside with the twelve-button keypad and the raspberry pi 3 model b will be used to accommodate the radio frequency identification scanner, global position sensor and the nucleo STM32 microcontroller to use the twelve-button keypad. This will all be housed in the enclosure made from acrylic and acrylonitrile butadiene styrene plastic. Some extra components will be a registered jack-forty-five ethernet cable with an ethernet to universal serial bus adapter. This will allow the Broadcom development platform to connect to a laptop via a remote desktop connection to configure settings for the sensors and effector. Some additional accessories that will enhance the features of the project will include; radio frequency identification tags for attaching to parts to scan in or out for inventory control, and an external active global position sensor antenna that will allow the sensor to have a boosted signal to get a position fix more faster and efficiently. The Two-Factor authentication will be implemented using both a soft and hard entry method. The user will be able to enter the five digits on the android device when prompted or enter them manually using the physical keypad. The keypad will itself be connected to a Raspberry Pi through the proprietary universal serial bus port with the STM32 microcontroller. The radio frequency identification scanner and the global positioning sensor will both be connected to the same Raspberry Pi using its general-purpose input/output pins and will both interface with the Real-Time database which will be used to retrieve both Student Information for radio frequency identification tags and current locations from the on-board global position sensor on their phone. The radio frequency identification scanner information will already have been loaded onto the database at the time of onboarding at the parts crib while the global position sensor coordinates will be pulled from the student’s phone when appropriate. An overall combination of these parts, components, and materials will lead to a successful build and presentation of the project.

### 3.1.2 Manufacturing

### 3.1.3 Tools and Facilities

### 3.1.4 Shipping, duty, taxes

### 3.1.5 Time expenditure

Working time versus lead time.

## 3.2 Development Platform

### 3.2.1 Mobile Application

Status

/1 Hardware present?

/1 Memo by student A + How did you make your Mobile Application? (500 words)

/1 Login activity

/1 Data visualization activity

/1 Action control activity

Include screenshots such as Figure 1. Testing. Progress.


Figure 1. By Android Studio - https://developer.android.com/studio/, CC BY-SA 4.0, https://commons.wikimedia.org/w/index.php?curid=74094999

### 3.2.2 Image/firmware

Status

/1 Hardware present?

/1 Memo by student B + How did you make your Image/firmware? (500 words)

/1 Code can be run via serial or remote desktop

/1 Wireless connectivity

/1 Sensor/effector code on repository

### 3.2.3 Breadboard/Independent PCBs

Status

/1 Hardware present?

/1 Memo by student C + How did you make your hardware? (500 words)

/1 Sensor/effector 1 functional

/1 Sensor/effector 2 functional

/1 Sensor/effector 3 functional

The initial schematic design, Figure 2, based on datasheets (Bosch Sensortec, 2019) led to a breadboard layout Figure 3 that was realized Figure 4.

How did you build your Prototype: Breadboard?

Then a PCB was designed, Figure 5, and populated (Figure 6). Bill of Materials, Case, Time commitment. Testing. Progress.


Figure 2. Initial schematic. This work is a derivative of "http://fritzing.org/parts/" by Fritzing, used under CC:BY-SA 3.0.


Figure 3. This work is a derivative of "http://fritzing.org/parts/" by Fritzing, used under CC:BY-SA 3.0.


Figure 4. Breadboard prototype.

### 3.2.4 Printed Circuit Board

Demo

/1 Hardware present?

/1 PCB Complete and correct

/1 PCB Soldered wire visible but trim, no holes or vacancies

/1 PCB Tested with multimeter

/1 PCB Powered up

How did you build your Prototype: PCB?


Figure 5. PCB design This work is a derivative of "http://fritzing.org/parts/" by Fritzing, used under CC:BY-SA 3.0.


Figure 6. Humber Sense Hat Prototype PCB.

### 3.2.5 Enclosure

Demo

/1 Hardware present?

/1 Case encloses development platform and custom PCB.

/1 Appropriate parts securely attached.

/1 Appropriate parts accessible.

/1 Design file in repository, photo in report.

How did you build your Prototype: Case?


Figure 7. Example enclosure.

## 3.3 Integration

Demo

/1 Hardware present?

/1 Data sent by hardware

/1 Data retrieved by mobile application

/1 Action initiated by mobile application

/1 Action recieved by hardware

Report

/1 Enterprise wireless connectivity (250)

/1 Database configuration (250 words)

/1 Security considerations (500 words)

/1 Unit testing (900 words)

/1 Production testing (100 words)

### 3.3.1 Enterprise Wireless Connectivity

How did you make a Database accessible by both your Prototype and Mobile Application?

### 3.3.2 Database Configuration

### 3.3.3 Security

### 3.3.4 Testing

Unit testing and Production testing.

# 4.0 Results and Discussions

Is your prototype perfect? What did you learn?

# 5.0 Conclusions

If you were making 1000 of these.

Report

/1 Hardware present?

/1 Checklist truthful

/1 Valid Comments

/1 Results and Discussion (500 words)

/1 Conclusion

# 6.0 References

Tejesh, B. S. S., & Neeraja, S. (2018). Warehouse inventory management system using IoT and open source framework. Alexandria Engineering Journal, 57(4), 3817–3823. https://doi.org/10.1016/j.aej.2018.02.003

Ben-Daya, M., Hassini, E., & Bahroun, Z. (2017). Internet of things and supply chain management: a literature review. International Journal of Production Research, 57(15–16), 4719–4742. https://doi.org/10.1080/00207543.2017.1402140

Hussain, K., Jhanjhi, N., Mati-ur-Rahman, H., Hussain, J., & Islam, M. H. (2019). Using a systematic framework to critically analyze proposed smart card based two factor authentication schemes. Journal of King Saud University - Computer and Information Sciences. https://doi.org/10.1016/j.jksuci.2019.01.015

Zelbst, P., & Sower, V. (2012). RFID for the supply chain and operations professional (1st;1; ed.). US: Business Expert Press.

# 7.0 Appendix

## 7.1 Firmware code

Demo

/1 Hardware present?

/3 Code runs concurrently for all sensors/effectors

/1 Project repository contains integrated code

Status

/1 Memo including updates

/1 Financial update

/1 Progress update

/1 Modified Code Files in Appendix

/1 Link to Complete Code in Repository

## 7.2 Application code

Demo

/1 Hardware present?

/1 Memo by student A

/1 Login activity

/1 Data visualization activity

/1 Action control activity

Report

/1 Login activity

/1 Data visualization activity

/1 Action control activity

/1 Modified Code Files in Appendix

/1 Link to Complete Code in Repository

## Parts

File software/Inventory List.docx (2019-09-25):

Inventory List

Analog_ICs

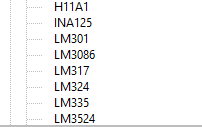
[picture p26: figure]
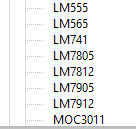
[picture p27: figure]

Boards

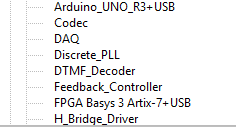
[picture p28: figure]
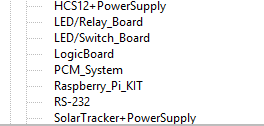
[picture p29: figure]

Cables

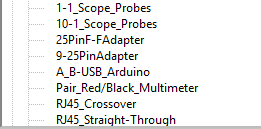
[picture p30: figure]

Capacitors

Digital ICs

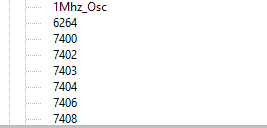
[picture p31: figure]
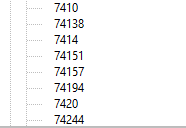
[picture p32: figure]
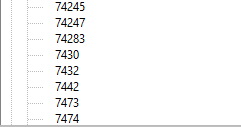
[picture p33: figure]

Diodes


Inductors

Misc


Motors

Resistors (1.2KOhm to 10 KOhm)


Resistors (12KOhm to 4.7MOhm)


Resistors(1Ohm to 1KOhm)


Potentiometer

RF Connectors


Tools


Transformers

Transistors/MOSFETs

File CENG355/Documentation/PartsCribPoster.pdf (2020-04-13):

# Gurkaran Padda, Mohamed Kore, Ricky Ramnath

# Parts Crib Management System

## ACKNOWLEDGEMENTS

## AIM

There will be many parts, components, and materials that will be used in this project. Firstly, there will be the sensors which include; the radio frequency identification scanner, global position sensor, and a twelve-button keypad. Each sensor and effector will be a key asset to this project. Some materials that will be used will include, laser cut acrylic, fiberglass epoxy resin with a copper foil bonded on to one or both sides for our PCB boards and acrylonitrile butadiene styrene plastic for the three-dimensional printed parts that will be used with the acrylic to make a feasible enclosure to house our sensors. For our development platform, we will be using a raspberry pi three model b. This will all be housed in the enclosure made from acrylic. Some additional accessories that will enhance the features of the project will include; radio frequency identification tags for attaching to parts to scan in or out for inventory control, and an external active global position sensor antenna that will allow the sensor to have a boosted signal to get a position fix more faster and efficiently. Most of the tools required for testing the hardware, are either already given to us in our classroom or we already have it with us at all times in our toolboxes. For testing on our hardware’s PCB Board, we will be using multimeters in order to find any connection continuity errors. Some other components that we may need to borrow for our hardware design, such as the helping hand for holding the PCB board, will be acquired from the parts crib.

## INTRODUCTION

The parts crib management system will implement a system that will allow the parts crib to keep an electronic catalogue of items loaned out to students. Students will be able to use a mobile android-based application to see what items are available and to request them using their student credentials. An RFID Scanner, GPS Sensor, and a Keypad System will allow us to achieve this. Our goal is to make this a more efficient and easier way of borrowing parts from the parts crib. It is a goal of our group to make this project industry worthy for any application. We are assuming we’re capable of putting RFID tags on everyone’s student ID in the parts management system. We can also assume that the inventory of the parts crib is given to us so we’re able to put it into our database for when it comes to distribution of parts. We’re dependent on the Admins at the parts crib to be able to read the system and be able to handle the intake of item requests given to them by the users.

## METHOD

We have integrated our most of our components into a single board and have updated our codes into a single python script. The code we’ve implemented allows the RC522 RFID to read inputs from the RFID chip and print it to the screen with included details such as the unique ID of each chip and will eventually display necessary information from the database like name and a list of signed out components. It also allows the GPS Breakout to write real time updates of location to the screen, which will be implemented to retrieve data such as sign-out times from the database. Finally, the code for the Keypad allows input into the script, which will be eventually integrated into the database authentication component. The updated code including all of components can be found at our GitHub repository. In terms of progress of troubleshooting our code, we’ve resolved any big issues and will likely troubleshoot any remaining errors while also cleaning up the code and have them corrected by the deadline. As for finance, our budget has not changed, and no added costs have taken place since the declaration of our required resources.

## RESULTS

We produced four main views/tabs that the user should need on the mobile app, and we should keep it no more than four in order to avoid confusion. The four views we decided on for the mobile app was a home tab, a loans tab, a account tab, and a help tab, any other small details that we would need or plan on implementing in the future can be put into the settings menu.

We have finished the creation of the app and database. When items gets requested on the app, it gets sent to the database when there it will be stored and associated with a unique iq, the name of the requested item, timestamps, and a unique code. All of this is stored in a category that holds information such as humber email address, student name, student number, an a iq number associated with the order. The app is fully functional along side of the database.

## PRINTING

For the enclosure, we designed a 175mm x 138mm x 43mm
acrylic case to be laser cut in order to mount and house the Raspberry Pi 3 B+ and to provide ports for connecting power and an antenna extension for the GPS sensor. Furthermore, there is an opening on the top portion of the design to allow for keypad to be accessed.

Additionally, as the Keypad is mounted to the PCB through its pins at the bottom, it is cantilevered on the open side of the enclosure, requiring the use of a support. This support is provided by a 3D printed bracket.

## CONCLUSIONS

We had planned on developing a web-based media designed for the use for employees behind the parts crib in order to manage inventory and regulate orders. As of now there’s no foreseeable deployment of the Parts Crib management system happening due to the events currently happening.

Database with info
being sent from the
application

There are
subcategories for
students and their
requested parts

Frizting PCB
General concept

Home Menu Activity along
With other major tabs

Flood activity for when the parts crib is closed

Finalized PCB board
With our sensors

Website used by Parts Crib Staff to assign RFID tags to students and track
requests.

CDR vector file for laser
cut enclosure

STL file for 3D printed
bracket.

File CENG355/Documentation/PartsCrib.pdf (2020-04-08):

# Gurkaran Padda, Mohamed Kore, Ricky Ramnath

# Parts Crib Management System

## ACKNOWLEDGEMENTS

## AIM

There will be many parts, components, and materials that will be used in this project. Firstly, there will be the sensors which include; the radio frequency identification scanner, global position sensor, and a twelve-button keypad. Each sensor and effector will be a key asset to this project. Some materials that will be used will include, laser cut acrylic, fiberglass epoxy resin with a copper foil bonded on to one or both sides for our PCB boards and acrylonitrile butadiene styrene plastic for the three-dimensional printed parts that will be used with the acrylic to make a feasible enclosure to house our sensors. For our development platform, we will be using a raspberry pi three model b. This will all be housed in the enclosure made from acrylic. Some additional accessories that will enhance the features of the project will include; radio frequency identification tags for attaching to parts to scan in or out for inventory control, and an external active global position sensor antenna that will allow the sensor to have a boosted signal to get a position fix more faster and efficiently. Most of the tools required for testing the hardware, are either already given to us in our classroom or we already have it with us at all times in our toolboxes. For testing on our hardware’s PCB Board, we will be using multimeters in order to find any connection continuity errors. Some other components that we may need to borrow for our hardware design, such as the helping hand for holding the PCB board, will be acquired from the parts crib.

## INTRODUCTION

The parts crib management system will implement a system that will allow the parts crib to keep an electronic catalogue of items loaned out to students. Students will be able to use a mobile android-based application to see what items are available and to request them using their student credentials. An RFID Scanner, GPS Sensor, and a Keypad System will allow us to achieve this. Our goal is to make this a more efficient and easier way of borrowing parts from the parts crib. It is a goal of our group to make this project industry worthy for any application. We are assuming we’re capable of putting RFID tags on everyone’s student ID in the parts management system. We can also assume that the inventory of the parts crib is given to us so we’re able to put it into our database for when it comes to distribution of parts. We’re dependent on the Admins at the parts crib to be able to read the system and be able to handle the intake of item requests given to them by the users.

## METHOD

We have integrated our most of our components into a single board and have updated our codes into a single python script. The code we’ve implemented allows the RC522 RFID to read inputs from the RFID chip and print it to the screen with included details such as the unique ID of each chip and will eventually display necessary information from the database like name and a list of signed out components. It also allows the GPS Breakout to write real time updates of location to the screen, which will be implemented to retrieve data such as sign-out times from the database. Finally, the code for the Keypad allows input into the script, which will be eventually integrated into the database authentication component. The updated code including all of components can be found at our GitHub repository. In terms of progress of troubleshooting our code, we’ve resolved any big issues and will likely troubleshoot any remaining errors while also cleaning up the code and have them corrected by the deadline. As for finance, our budget has not changed, and no added costs have taken place since the declaration of our required resources.

## RESULTS

We produced four main views/tabs that the user should need on the mobile app, and we should keep it no more than four in order to avoid confusion. The four views we decided on for the mobile app was a home tab, a loans tab, a account tab, and a help tab, any other small details that we would need or plan on implementing in the future can be put into the settings menu.

We have finished the creation of the app and database. When items gets requested on the app, it gets sent to the database when there it will be stored and associated with a unique iq, the name of the requested item, timestamps, and a unique code. All of this is stored in a category that holds information such as humber email address, student name, student number, an a iq number associated with the order. The app is fully functional along side of the database.

## PRINTING

For the enclosure, we designed a 175mm x 138mm x 43mm
acrylic case to be laser cut in order to mount and house the Raspberry Pi 3 B+ and to provide ports for connecting power and an antenna extension for the GPS sensor. Furthermore, there is an opening on the top portion of the design to allow for keypad to be accessed.

Additionally, as the Keypad is mounted to the PCB through its pins at the bottom, it is cantilevered on the open side of the enclosure, requiring the use of a support. This support is provided by a 3D printed bracket.

## CONCLUSIONS

We had planned on developing a web-based media designed for the use for employees behind the parts crib in order to manage inventory and regulate orders. As of now there’s no foreseeable deployment of the Parts Crib management system happening due to the events currently happening.

Database with info
being sent from the
application

There are
subcategories for
students and their
requested parts

Frizting PCB
General concept

Home Menu Activity along
With other major tabs

Flood activity for when the parts crib is closed

Finalized PCB board
With our sensors

Website used by Parts Crib Staff to assign RFID tags to students and track
requests.

CDR vector file for laser
cut enclosure

STL file for 3D printed
bracket.

## Commonly used logos


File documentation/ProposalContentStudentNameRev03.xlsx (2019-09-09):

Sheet: DataEntry
Submission Date | 2019-09-10
Project Name | GPS Sensor
Student Names | Ricky Ramnath
Project repository | https://rickyramnath97.github.io/gps/
SensorsEffectors choices | Adafruit Ultimate GPS Breakout - 66 channel w/10 Hz updates - Version 3
The database will store | Location of each parts crib. Student Names, ID's, E-Mail Adresses, and a randomly genrated pin for easy identification.
The mobile device functionality will include | To enhance the user experience, having a GPS sensor is crucial to detect which parts crib the data belongs to aswell as allow students to find out where they are located and how far they are from the parts crib in the app. Will also show different parts cribs stations if the parts crib expands to different parts of campus in the future.
I will be collaborating with the following company/department | Prototype Lab, Raspberry Pi or Arduino.
My group in the winter semester will include | Mohammed Kore, Gurkaran Padda
50 word problem statement | New students tend to get lost around campus. As a first-year engineering student, I found it difficult to navigate my way throughout campus. This can result in many students getting lost while trying to find the parts crib. Once they find the parts crib, the lab would have most likely have started and they would lose valuable time to complete their lab.
100 words of background | I would like to use this sensor with my project because I have always been fascinated with how you can hook up a GPS module to a microcontroller development platform (Raspberry Pi). I started to find interest in this from my Embedded Systems class when we made the solar panel tracking system. Throughout the summer I have been tinkering with many ways to use this at work and found that there can be so many ways to use such a little sensor. Since then, I have decided to incorporate this with my hardware production class and my final capstone project. I am very excited to work on this.
Current product APA citation | Adafruit Industries. (n.d.). Adafruit Ultimate GPS Breakout - 66 channel w/10 Hz updates. Retrieved from https://www.adafruit.com/product/746
Existing research IEEE paper APA citation | Liu, J., Priyantha, B., Hart, T., & Jin, Y. (2015, July 22). CO-GPS: Energy Efficient GPS Sensing with Cloud Offloading. Retrieved from https://ieeexplore.ieee.org/document/7164360
Brief description of planned purchases | Raspberry Pi (Already Purchased), Adafruit Ultimate GPS to determine location of parts crib.
Solution description | The goal is to make the project scalable from one location to several. Students will no longer have trouble trying to find the parts crib. They can easily check the nearest parts crib around them and they will be able to grab their parts and be in class on time to complete their assignments.

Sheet: DataBase
Submission Date | Project Name | Student Names | Project repository | SensorsEffectors choices | The database will store | The mobile device functionality will include | I will be collaborating with the following company/department | My group in the winter semester will include | 50 word problem statement | 100 words of background | Current product APA citation | Existing research IEEE paper APA citation | Brief description of planned purchases | Solution description
43718 | GPS Sensor | Ricky Ramnath | https://rickyramnath97.github.io/gps/ | Adafruit Ultimate GPS Breakout - 66 channel w/10 Hz updates - Version 3 | Location of each parts crib. Student Names, ID's, E-Mail Adresses, and a randomly genrated pin for easy identification. | To enhance the user experience, having a GPS sensor is crucial to detect which parts crib the data belongs to aswell as allow students to find out where they are located and how far they are from the parts crib in the app. Will also show different parts cribs stations if the parts crib expands to different parts of campus in the future. | Prototype Lab, Raspberry Pi or Arduino. | Mohammed Kore, Gurkaran Padda | New students tend to get lost around campus. As a first-year engineering student, I found it difficult to navigate my way throughout campus. This can result in many students getting lost while trying to find the parts crib. Once they find the parts crib, the lab would have most likely have started and they would lose valuable time to complete their lab. | I would like to use this sensor with my project because I have always been fascinated with how you can hook up a GPS module to a microcontroller development platform (Raspberry Pi). I started to find interest in this from my Embedded Systems class when we made the solar panel tracking system. Throughout the summer I have been tinkering with many ways to use this at work and found that there can be so many ways to use such a little sensor. Since then, I have decided to incorporate this with my hardware production class and my final capstone project. I am very excited to work on this. | Adafruit Industries. (n.d.). Adafruit Ultimate GPS Breakout - 66 channel w/10 Hz updates. Retrieved from https://www.adafruit.com/product/746 | Liu, J., Priyantha, B., Hart, T., & Jin, Y. (2015, July 22). CO-GPS: Energy Efficient GPS Sensing with Cloud Offloading. Retrieved from https://ieeexplore.ieee.org/document/7164360 | Raspberry Pi (Already Purchased), Adafruit Ultimate GPS to determine location of parts crib. | The goal is to make the project scalable from one location to several. Students will no longer have trouble trying to find the parts crib. They can easily check the nearest parts crib around them and they will be able to grab their parts and be in class on time to complete their assignments.

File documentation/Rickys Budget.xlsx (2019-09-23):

Ricky Ramnath N01094968
GPS Sensor Parts
Description | Source | Part # | $USD Price | $CAD Price | $USD Total | $CAD Total | Link
SMA to uFL/u.FL/IPX/IPEX RF Adapter Cable | Adafruit | 851 | $3.95 |  |  |  | https://www.adafruit.com/product/851
Adafruit Ultimate GPS Breakout - 66 channel w/10 Hz updates (Version 3) | Adafruit | 746 | $39.95 |  |  |  | https://www.adafruit.com/product/746
GPS Antenna - External Active Antenna - 3-5V 28dB 5 Meter SMA | Adafruit | 960 | $14.95 |  |  |  | https://www.adafruit.com/product/960
Tax and Customs |  |  | $7.64
Shipping and Handling |  |  | $22.05
 |  |  |  |  | $88.54 | $117.42
Raspberry Pi 3 Starter Kit | Already Aquired | N/A | N/A | N/A | N/A | N/A
Humber Parts kit | Bookstore | N/A | N/A | N/A | N/A | N/A
PCB | Prototype Lab | N/A | N/A | N/A | N/A | N/A
Grand Total (using CAD$1=USD$0.75) |  |  |  |  | $117.42

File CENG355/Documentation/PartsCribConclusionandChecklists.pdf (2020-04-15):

Reports and Discussions

Is your prototype perfect? What did you learn?

The primary functions of the physical prototype are working correctly. While an

encasement wasn’t able to be produced, the PCB has no physical issues such as

broken solder contacts or unintended connections. The sensors are working as

expected, although the GPS sensor required the use of an external antenna to be able

to obtain a signal. The most significant hardware issue with our prototype came during

the development process when the Nucleo-32 development board that interfaced with

the keypad failed to properly communicate with the Raspberry Pi using i2c and

eventually failed altogether. This required us to directly interface with the Keypad with

the Raspberry Pi.

Furthermore, as our team began to integrate the prototype into the rest of the system

and worked through the sign-in/pick-up flow we discovered some design aspects that

could be improved upon. Firstly, there is no way to indicate the success status of an

RFID tap or keypad entry to students signing in on the prototype, as there are no

programmable lights or speakers built into the Raspberry Pi or included on the PCB.

The initial plan was to have the system be Raspberry Pi configured to run headless and

the web-connected computer at the Parts Crib would provide audible status feedback

using the computer’s feedback, however, our dashboard needs to incorporate an alert

system for incoming requests and it became clear that having an audible alert for both

sign-ins and incoming requests would overwhelm the staff and make it difficult to

distinguish what the alert was for. Additionally, there is no way for users to intuitively reset or correct an incorrect Keypad entry or reset the sign-in process altogether. We

discussed assigning one of the unused keys on the Keypad (* and #) for this purpose

but decided it would slow the process down further as there is no way for students to

know the current state of the login system (as stated above). Another design obstacle

we came across during the development of the platform was the use of the Firebase

real-time database to store our data. As the database stores data in the form of

documents using JSON notation, it made it more difficult to store inventory, user and

request information. While there are methods to flattening data in NoSQL databases, a

traditional relational database would have better served the needs of our platform.

Conclusion

In conclusion, while the social distancing requirements and closure of facilities due to

the SARS-CoV2 outbreak have created challenges for our team, we’ve still managed to

accomplish much of what we set out to do. The issues surrounding working remotely

with team members on different components of the project are relatable to those that

arise in larger workplaces where multiple teams have to coordinate with one another to

complete projects. We feel that the communication skills developed in producing

deliverables over the latter period of this course lend themselves well to the workplace

and can be valuable to future employers. Furthermore, the lessons learned during the

integration phase of this project taught us the value of taking the fully integrated system

(software and hardware) and how it’ll be used by others into account when designing

the prototype. Our team would like to thank and acknowledge our instructors Austin

Tian and Kristian Medri for providing us with the necessary support to complete this

project over the course of our final school year.

April 14/15 Results and Discussion, Conclusion, Prescreening, Report Mechanics and

Structure Checklist: (section 10 of https://www.oacett.org/getmedia/9f9623ac-73ab-

4f99-acca-0d78dee161ab/TR_GUIDELINES_Final.pdf.aspx (https://www.oacett.org/getmedia/9f9623ac-73ab-4f99-acca-0d78dee161ab/TR_GUIDELINES_Final.pdf.aspx)) (https://www.oacett.org/getmedia/9f9623ac-73ab-4f99-acca-0d78dee161ab/TR_GUIDELINES_Final.pdf.aspx) your

repository/Documentation/GroupNameConclusionandChecklists.pdf

Prescreening Checklist

1. Has a Proposal for a Technology Report been submitted and accepted and a copy of the approved proposal included in the Technology Report?

Yes, we had submitted a proposal in the previous semester, approved by

professor Austin Tian who was our previous instructor for the first half of the

project in Fall 2019. (CENG 319,317). Yes, a copy of the approved proposal is

included in the report on Github.

2. Has the Technology Report been submitted within one year since the proposal was approved?

Yes.

3. Is the Technology Report consistent with the Proposal (as approved and with the comments and suggestions made by the proposal reviewer)?

Yes.

4. Is the Technology Report typed, double-spaced and justified left?

Yes.

5. Has a 12 point Arial, Univers, or similar Sans Serif font been used?

Yes, the font type used is Arial.

6. Is the body of the report a minimum of 3,000 words?

Yes.

7. Are the components included and in the following order: Title Page; Declaration of

Authorship; Approved Proposal; Abstract/Executive Summary; Table of Contents;

Lists of Illustrations/Diagrams; Body of the TR; Conclusion(s), and if applicable

Recommendation(s); Bibliography/Technical References; and Appendices?

Yes.

8. Is there a signed Declaration of Authorship?

No, because our group decided to not upload private signatures for security

purposes to our repository as it is public to everyone.

9. Is the report dated?

Yes, date of April 15th
,2020 to coincide with the final report submission.
10. Is the Technology Report current? (The Technology Report should be less than 5 years old.)

Yes.

11. Is there a Title Page?

Yes.

12. Is there a Table of Contents?

Yes.

13. Does the Table of Contents correctly reflect the Components: Headings,

Illustrations/Diagrams and Appendices?

Yes.

14. Are the pages numbered with appropriate page breaks?

Yes, correctly numbered with odd page breaks for the start of each next section

of the report.

15. Is there an Abstract/Executive Summary and Introduction?

Yes.

16. Does the body of the report contain Section Headings?

Yes.

17. Are there Conclusion(s), and if applicable, Recommendation(s)?

Yes.

18. Is there a Bibliography with appropriately cited Technical References?

Yes, there is a References section with properly cited references used for the

project in APA format.

Report Mechanics and Structure Checklist:

1. Does the Title, in ten words or less, inform readers of the precise subject matter contained in the TR? A title should be concise and include key words for indexing.

No, it is 13 words.

2. Does the Abstract or Executive Summary provide a brief overview of the report in approximately 75 to 100 words?

It is approximately 191 words.

3. Does the Abstract or Executive Summary summarize the Conclusion(s), and if applicable, the Recommendation(s)?

Yes.

4. Does the Introduction state the reason the work was undertaken? What is the industry, organization or context? What is the problem?

Yes.

5. Does the Introduction cover the scope of the report? What is included and /or admitted, and what procedures are used?

Yes.

6. Do the headings and subheadings in the Body adequately and accurately describe the section or subsection content?

Yes.

7. Does the Body include information regarding the methodology? Does it indicate materials, equipment and procedures used and why they were selected over alternatives? Is there sufficient detail so that that the methodology can be duplicated by others?

Yes.

8. Does the Body include recent research findings?

No, there were not any new findings as we’ve done extensive research from semester five in CENG 317 and CENG 319.

9. Does the Body include results/data from the study?

Yes.

10. Are illustrations, tables, diagrams and charts clearly drawn, labelled and numbered?

Yes.

11. Is each Conclusion, and if applicable, each Recommendation, stated in a separate paragraph and in a positive way? Conclusions should not be qualified with “it seems”, “probably”, “it may be”, or other words that dilute the strength of the conclusion.

Yes.

12. Are the References/Bibliography complete? All materials referenced in the TR should be represented in the list of References/Bibliography.

Yes.

13. Do the Appendices support the study? Do the Appendices include substantiating data and calculations? Extraneous material should not be included.

Yes.

14. Is the spelling correct? Has either the Canadian or USA spelling system been used consistently through the TR.

Yes, we fixed any typos, spelling, and grammatical errors based on feedback we

received from our weekly deliverables.

15. Is the language free of jargon? Are acronyms properly introduced? Are abbreviations appropriate and correct? Can someone without specific expertise in the field read and understand the TR?

Yes.

16. Is the same voice (I, one, person, etc.) used consistently throughout the Technology Report? There should not be any switching from third person to first person or vice versa.

Yes.

17. Do the grammar and punctuation follow normally accepted rules of use? Use Ron

Blicq’s text Technically Write or a similar grammar reference as a guide.

Yes.

18. Are thoughts and illustrations/diagrams/charts that do not belong to the writer properly identified and footnoted in the text? Are quotations indicated correctly? Are the authors referenced in footnotes and/or reference list? Do they include the author’s name, the title of the article/book, the date of publication, and the publisher?

Yes.

Report Content:

This section evaluates the quality of the work completed when addressing the problem

statement/hypothesis. Fulfillment of these criteria leads to a TR that makes a

contribution to the field under study.

1. Are the Problem Statement and Hypothesis significant to the current state of the field/industry?

Yes.

2. Is the Methodology scientifically sound?

Yes.

3. Are the engineering technology and applied science principles used in the

Methodology and Analysis appropriate to the subject area?

Yes.

4. Are the Data and/or Results complete?

Yes.

5. Have the Mathematical formulae been applied appropriately?

No, mathematical formulae were not needed for this project.

6. Are the Mathematical calculations done correctly and accurately?

No, there were no calculations in this project.

7. Are the Illustrations/Diagrams/Charts technically correct?

Yes.

8. Is the Analysis of the results correct?

Yes.

9. Is the Analysis complete?

Yes.

10. Are the Conclusion(s), and if applicable the Recommendation(s), free of discussion, explanation and opinion?

Yes, expressed only in facts.

11. Do the Conclusion(s), and if applicable the Recommendation(s), relate to and resolve the Problem Statement and/or Hypothesis?

Yes.

12. Are the Conclusion(s), and if applicable the Recommendation(s), logical?

Yes, and next-steps are considered for marketing/client purchase, ways to

improve the final product, and build on existing features for a wider consumption

of the public and move the product into purchasing.

13. Does the report make a contribution to the industry/field of study?

Yes.

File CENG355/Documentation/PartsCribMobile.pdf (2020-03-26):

7.2 Application code

Code Location: https://github.com/c3ko/Parts-Crib-Android

Demo

/1 Hardware present?

/1 Memo by student A

/1 Login activity

/1 Data visualization activity

/1 Action control activity

Report

/1 Login activity

/1 Data visualization activity

/1 Action control activity

/1 Modified Code Files in Appendix

/1 Link to Complete Code in Repository

The Login Activity (along with a registration and forgotten password activity) were

already implemented in the CENG 318. Those activities along with the ability to create

requests was also demonstrated during the previous android application status update.

In the intervening time we’ve further added an activty to input the six digit pin required to

retrieve requested parts instead of using the keypad. The acitvity updates and sets the

current pin being required by the parts crib through the Firebase database so that each key press on either the keypad or the phone will be updated throughout the system in

real time. Furthermore, we’ve implemented an activity to display the current location of the part-crib in real time by reading the GPS coordinates from the GPS sensor from the

Firebase database through the android application.

7.2.1 KeypinActivity.java

package com.partscrib.partscribmanagementsystem;

import androidx.annotation.NonNull;

import androidx.annotation.Nullable;

import androidx.appcompat.app.AppCompatActivity;

import com.davidmiguel.numberkeyboard.NumberKeyboard;

import com.davidmiguel.numberkeyboard.NumberKeyboardListener;

import com.google.android.gms.tasks.OnFailureListener;

import com.google.android.gms.tasks.OnSuccessListener;

import com.google.firebase.database.ChildEventListener;

import com.google.firebase.database.DataSnapshot;

import com.google.firebase.database.DatabaseError;

import com.google.firebase.database.DatabaseReference;

import com.google.firebase.database.FirebaseDatabase;

import com.google.firebase.database.ValueEventListener;

import com.partscrib.partscribmanagementsystem.model.ExpandableListPartData;

import com.partscrib.partscribmanagementsystem.model.PartExpandableListAdapter;

import com.partscrib.partscribmanagementsystem.model.PartModel;

import android.os.Bundle;

import android.service.autofill.UserData;

import android.util.Log;

import android.widget.TextView;

import org.w3c.dom.Text;

import java.util.ArrayList;

import static

com.partscrib.partscribmanagementsystem.Login.USER_NAME_MESSAGE;

public class KeypinActivity extends AppCompatActivity {

NumberKeyboard numberKeyboard;

TextView textView;

String keypin = "";

private FirebaseDatabase db;

private DatabaseReference dbRef;

@Override

protected void onCreate(Bundle savedInstanceState) {

super.onCreate(savedInstanceState);

setContentView(R.layout.activity_keypin);

numberKeyboard = (NumberKeyboard) findViewById(R.id.numberKeyboard);

textView = (TextView) findViewById(R.id.keypin_text);

numberKeyboard.showRightAuxButton();

db = FirebaseDatabase.getInstance();

String user = getIntent().getStringExtra(USER_NAME_MESSAGE);

String path = "userdata/" + user + "/currentPinEntry";

dbRef = db.getReference(path);

numberKeyboard.setListener(new NumberKeyboardListener() {

@Override

public void onNumberClicked(int number) {

if (keypin.length() < 6){

setCurrentPin(number);

textView.setText(keypin);

}

else {

}

}

@Override

public void onLeftAuxButtonClicked() {

}

@Override

public void onRightAuxButtonClicked() {

}

});

getCurrentPin();

}

public void setCurrentPin(int number){

keypin = keypin + number;

// Submit pin to firebase

dbRef.setValue(keypin);

}

public void getCurrentPin(){

dbRef.addValueEventListener(new ValueEventListener() {

@Override

public void onDataChange(@NonNull DataSnapshot dataSnapshot) {

keypin = dataSnapshot.getValue(String.class);

textView.setText(keypin);

}

@Override

public void onCancelled(@NonNull DatabaseError databaseError) {

}

});

}

}

7.2.2 MapActivity.java

package com.partscrib.partscribmanagementsystem;

import androidx.annotation.NonNull;

import androidx.appcompat.app.AppCompatActivity;

import android.os.Bundle;

import com.google.android.gms.maps.CameraUpdateFactory;

import com.google.android.gms.maps.GoogleMap;

import com.google.android.gms.maps.MapView;

import com.google.android.gms.maps.MapsInitializer;

import com.google.android.gms.maps.OnMapReadyCallback;

import com.google.android.gms.maps.model.BitmapDescriptorFactory;

import com.google.android.gms.maps.model.LatLng;

import com.google.android.gms.maps.model.MarkerOptions;

import com.google.firebase.database.DataSnapshot;

import com.google.firebase.database.DatabaseError;

import com.google.firebase.database.DatabaseReference;

import com.google.firebase.database.FirebaseDatabase;

import com.google.firebase.database.ValueEventListener;

import static

com.partscrib.partscribmanagementsystem.Login.USER_NAME_MESSAGE;

public class MapActivity extends AppCompatActivity {

class Location {

private String latitude;

private String longitude;

public Location(String latitude, String longitude) {

this.latitude = latitude;

this.longitude = longitude;

}

public String getLatitude() {

return latitude;

}

public void setLatitude(String latitude) {

this.latitude = latitude;

}

public String getLongitude() {

return longitude;

}

public void setLongitude(String longitude) {

this.longitude = longitude;

}

}

Location location;

MapView mMapView;

GoogleMap googleMap;

FirebaseDatabase db;

DatabaseReference dbRef;

@Override

protected void onCreate(Bundle savedInstanceState) {

super.onCreate(savedInstanceState);

setContentView(R.layout.activity_map);

db = FirebaseDatabase.getInstance();

String path = "newsBulletin/location";

dbRef = db.getReference(path);

mMapView = (MapView) findViewById(R.id.mapView2);

mMapView.onCreate(savedInstanceState);

mMapView.onResume(); // needed to get the map to display immediately

dbRef.addValueEventListener(new ValueEventListener() {

@Override

public void onDataChange(@NonNull DataSnapshot dataSnapshot) {

location = dataSnapshot.getValue(Location.class);

}

@Override

public void onCancelled(@NonNull DatabaseError databaseError) {

}

});

try {

MapsInitializer.initialize(getApplicationContext());

} catch (Exception e) {

e.printStackTrace();

}

mMapView.getMapAsync(new OnMapReadyCallback() {

@Override

public void onMapReady(GoogleMap mMap) {

googleMap = mMap;

// For dropping a marker at a point on the Map

//LatLng Humber = new LatLng(43.724330436,-79.605497578);

LatLng Humber = new LatLng(Float.parseFloat(location.longitude),

Float.parseFloat(location.latitude));

googleMap.addMarker(new MarkerOptions()

.position(Humber)

.icon(BitmapDescriptorFactory.fromResource(R.drawable.humber))

.title("Welcome to Humber College"));

googleMap.moveCamera(CameraUpdateFactory.newLatLngZoom(Humber,

(float) 6.0));

googleMap.setMinZoomPreference(2.0f);

googleMap.setMaxZoomPreference(30.0f);

googleMap.setTrafficEnabled(true);

}

});

}

@Override

public void onResume() {

super.onResume();

mMapView.onResume();

}

@Override

public void onPause() {

super.onPause();

mMapView.onPause();

}

@Override

public void onDestroy() {

super.onDestroy();

mMapView.onDestroy();

}

@Override

public void onLowMemory() {

super.onLowMemory();

mMapView.onLowMemory();

}

private double distance(double lat1, double lon1, double lat2, double lon2) {

double theta = lon1 - lon2;

double dist = Math.sin(deg2rad(lat1))

* Math.sin(deg2rad(lat2))

+ Math.cos(deg2rad(lat1))

* Math.cos(deg2rad(lat2))

* Math.cos(deg2rad(theta));

dist = Math.acos(dist);

dist = rad2deg(dist);

dist = dist * 60 * 1.1515;

return (dist);

}

private double deg2rad(double deg) {

return (deg * Math.PI / 180.0);

}

private double rad2deg(double rad) {

return (rad * 180.0 / Math.PI);

}

}

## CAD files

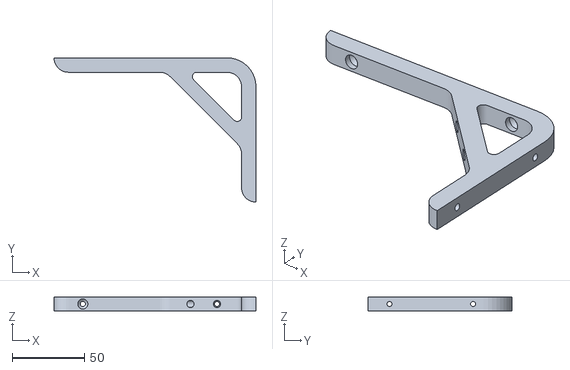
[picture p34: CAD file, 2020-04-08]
CENG355/Mechanical/PartsCribDesign3D.stl
140.0 x 100.0 x 10.0

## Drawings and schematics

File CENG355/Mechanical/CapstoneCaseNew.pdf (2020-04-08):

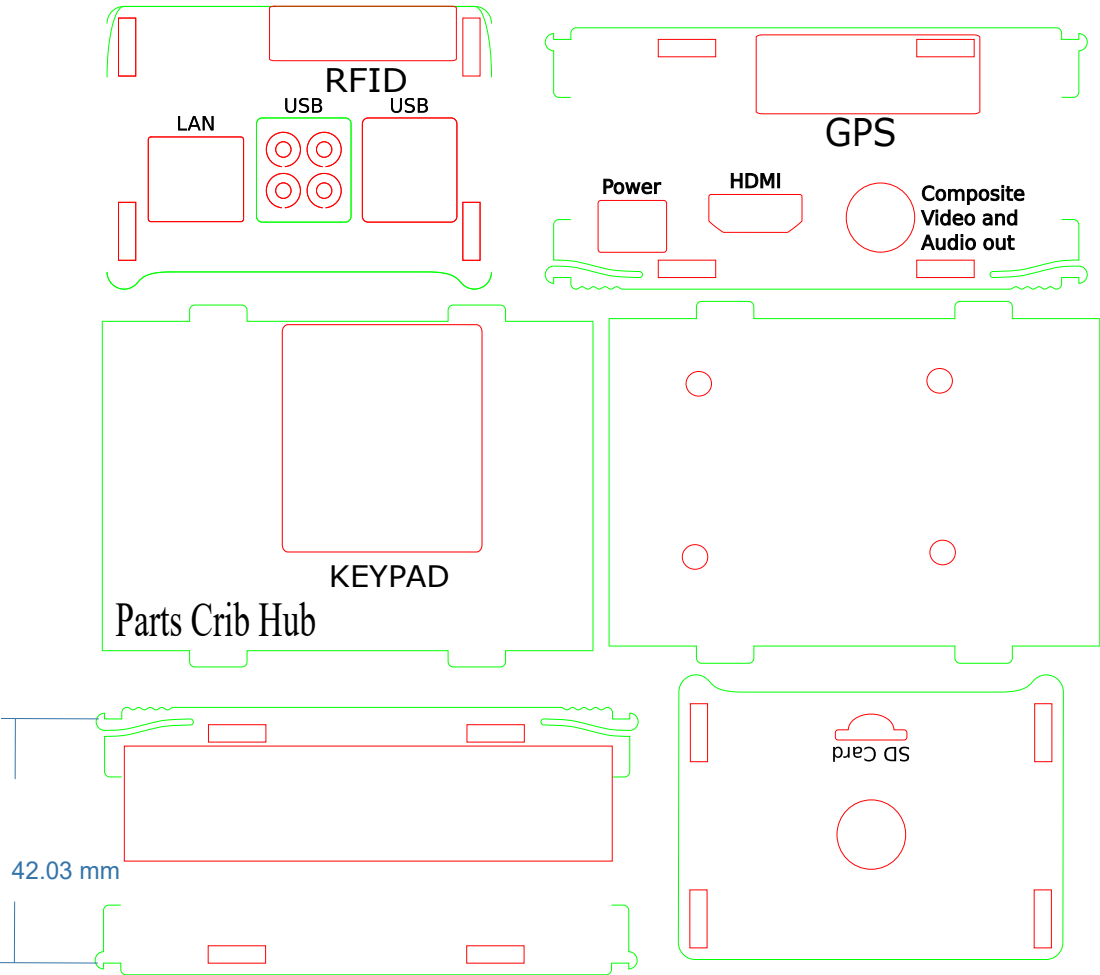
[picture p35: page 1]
RFID; KEYPAD; GPS

Parts Crib Hub

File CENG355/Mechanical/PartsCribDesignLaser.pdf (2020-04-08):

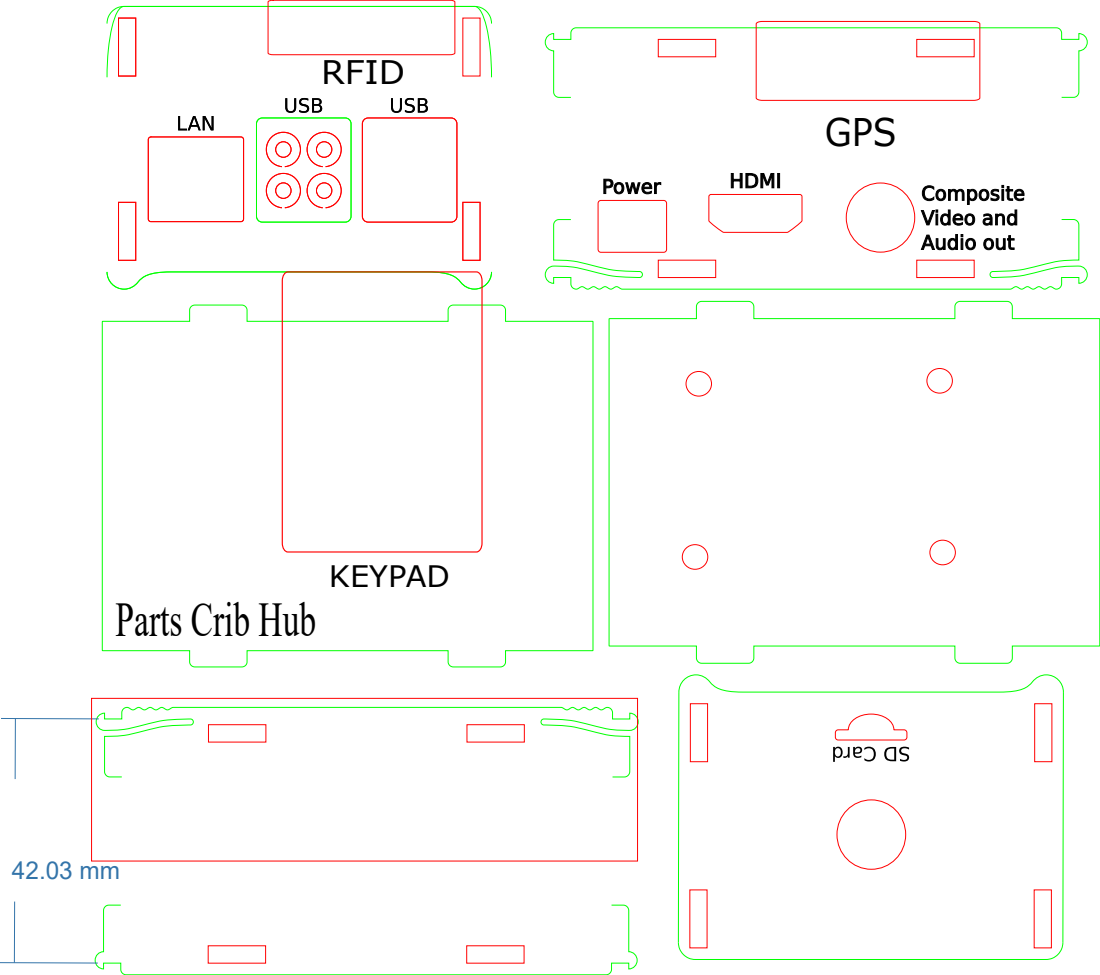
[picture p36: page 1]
RFID; KEYPAD; GPS

Parts Crib Hub

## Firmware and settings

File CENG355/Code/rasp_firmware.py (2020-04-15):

"""@package docstring


"""

import pyrebase
#import pythonwifi.iwlibs import Wireless
from mfrc522 import SimpleMFRC522

#!/usr/bin/env python

#from gps import *
import os
import time
import subprocess
import sys
import board
import busio
import time
import adafruit_gps
import serial
import RPi.GPIO as GPIO
from pad4pi import rpi_gpio


from mfrc522 import SimpleMFRC522
API_KEY = os.getenv('API_KEY')


# Get Environment variables
o
GPIO.setmode(GPIO.BCM)
DEBUG = 1
LOGGER = 1

GPIO.setup(2, GPIO.IN)
GPIO.setup(3, GPIO.IN)
GPIO.setup(4, GPIO.IN)
GPIO.setup(17, GPIO.IN)
GPIO.setup(27, GPIO.IN)
#Read Tag
reader = SimpleMFRC522()


config = {
    "apiKey": API_KEY,
    "authDomain": "partscrib-2fe52.firebaseapp.com",
    "databaseURL": "https://partscrib-2fe52.firebaseio.com",
    "projectId": "partscrib-2fe52",
    "storageBucket": "partscrib-2fe52.appspot.com",
    "messagingSenderId": "154343080345",
    "appId": "1:154343080345:web:3c3060fc9d028b51e7d308"
}

firebase = pyrebase.initialize_app(config)
email = "partscribmanagement@gmail.com"  
password = "dummy123" 
auth = firebase.auth()

user_admin = auth.sign_in_with_email_and_password(email, password)
db = firebase.database()

current_student_sign_in = ""
current_student_onboarding =""

def gps():
    """
    Reads current coordinate values from GPS sensor and writes them to location data in database
    """
    #GPS
    # num = int(subprocess.check_output(['wc', '-l', "gps_data.txt"])[:-13])
    count = 0  
    try:
    # print lines
        gps_data = {"longitude": "43.724330436", "latitude": "-79.605497578"}
        db.child("newsBulletin/location/coordinates").update(gps_data)

    except (Exception):
        print("Done.\nExiting.")
        
    finally:
        GPIO.cleanup()
        print("Finished GPS")

entered_passcode = ""


def digit_entered(key):
    """
    Writes pressed key to current pin entry portion of database if there are less then 6 current numbers in the current pin entry.
    Otherwise updates database that full pin has been typed in.
    """
    global entered_passcode

    db.child(f"userdata/{current_student_sign_in}/").update({"currentPinEntry": entered_passcode})
    if  (len(entered_passcode) < 6):
        entered_passcode += str(key)
        #send to firebase
        print("Key Pressed: " + entered_passcode)
    else:
        db.child("newsBulletin/signIn/").update({"currentUID": "", "studentSigningIn": "false"})

def key_pressed(key):
    """
    Handler for key press event listener. Only allows key presses from 0-9.
    """
    try:
        int_key = int(key)
        if int_key >= 0 and int_key <= 9:
            digit_entered(key)

    except (Exception):
        pass
    
def keypad():
    """
    Initializes keypad and sets up configuration and listener
    """   
    KEYPAD = [
        [1, 2, 3],
        [4, 5, 6],
        [7, 8, 9],
        ["*", 0, "#"]
    ]

    ROW_PINS = [17, 27, 22, 24] # BCM numbering
    COL_PINS = [4, 18, 23] # BCM numbering

    factory = rpi_gpio.KeypadFactory()

    # Try factory.create_4_by_3_keypad
    # and factory.create_4_by_4_keypad for reasonable defaults

    keypad = factory.create_keypad(keypad=KEYPAD, row_pins=ROW_PINS, col_pins=COL_PINS)
    print("Keypad Intialized... Enter keys")
    keypad.registerKeyPressHandler(key_pressed)



def onboardRFID(uid):
    """
    Helper function for onboarding handler.
    Prompts and writes new onboarding student ID to tag
    """
    print("Tap tag to write UID to rfid chip...\n")
    # First read rfid id, text
    id, text = reader.read()
    # Overtite text to be student number and then update tag table
    reader.write(uid)
    db.child(f"tags/{id}/").set(uid)
    print(f'uid: {uid} written to tag\n')

def onboarding_stream_handler(message):
    """
    Database event handler that Handles onboarding flow.
    Retrieves current student to be proccessed.
    """
    if message["data"]["studentOnBoarding"] == "true":
        global current_student_onboarding
        current_student_onboarding = message["data"]["currentUID"]
        onboardRFID(current_student_onboarding)
        # set onboarding to false
        # set to false after onboarding complete
        db.child("newsBulletin/onBoarding/").update({"currentUID": "", "studentOnBoarding": "false"})
def signIn_stream_handler(message):
    """
    Database event handler that Handles sign-in flow.
    Retrieves current student to be proccessed and initiates keypad for pin entry
    """
    if message["data"]["studentSigningIn"] == "true":
        print("Sign-In initiated....")
        global current_student_sign_in
        current_student_sign_in = message["data"]["currentUID"]
        keypad()

        
def location_stream_handler(message):
    """
    Database event handler that Handles gps location update.
    Initiates GPS and updates current location.
    """
    if message["data"]["updateLocation"] == "true":
        gps()
        db.child("newsBulletin/location/").update({"updateLocation": "false"})

def main():
    """
    Main code block. Sets up event listeners to database. Runs in loop waiting for student to initiate sign-in process by tapping their
    RFID tag.
    """
    onboard_stream = db.child("newsBulletin/onBoarding/").stream(onboarding_stream_handler)
    signIn_stream = db.child("newsBulletin/signIn/").stream(signIn_stream_handler)
    location_stream = db.child("newsBulletin/location/").stream(location_stream_handler)
    while True:
        # Listen for signIn or onboarding event

        # Wait for user tap and set signIn to true to begin process for keypad entry
        try:
            id, text = reader.read()
            # Get the userID from tags table based on RFID id from database
            user_id = db.child(f'tags/{id}').get().val()
            print(f"Tag belongs to user {text}.")
            # update the current user id and singIn status at the location
            db.child("newsBulletin/signIn/").update({"currentUID": user_id['firebaseStudentID'], "studentSigningIn": "true" })

        except (Exception):
            print("Error: There was an error")
            continue
        finally:
            onboard_stream.close()
            signIn_stream.close()
            location_stream.close()

if __name__ == '__main__':
    main()
